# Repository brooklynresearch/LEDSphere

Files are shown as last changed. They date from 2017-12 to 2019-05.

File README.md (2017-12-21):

# LEDSphere
Code for controlling a matrix of LED Spheres

## Embedded Code
This folder is for any code that will be needed for the individual spheres

## Controller Code
This folder is for any code that will control full set of animations

## Eagle Files
This folder is for any PCB that will need to be designed for the spheres and control

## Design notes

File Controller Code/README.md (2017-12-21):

# Controller Code
Code for controlling a matrix of LED Spheres

## To Do
* Still defining communication protocol
* Waiting on Client for final animation and interaction

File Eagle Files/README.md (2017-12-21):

# Eagle Files
CAD files for PCB Designs.  All designs are currently tailored for the othermill and are more or less a one layer.

## Pixel Controller
Files for the individual Sphere.

## ENC28J60
Files for the ENC28J60 Breakout

## PoE Supply
Files to convert the PoE power to +5V

## To Do
* Determine Communications Protocol
* Design for SMD components and reduce profile

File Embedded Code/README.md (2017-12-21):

# Embedded Code
Code for controlling an individual sphere

## LEDSphere_NoComms_V01
Arduino Code for testing out individual functionality.  This code will need to change when proper communications protocol has been determined.

## libraries
Arduino libraries used in LEDSphere_NoComms_V01.

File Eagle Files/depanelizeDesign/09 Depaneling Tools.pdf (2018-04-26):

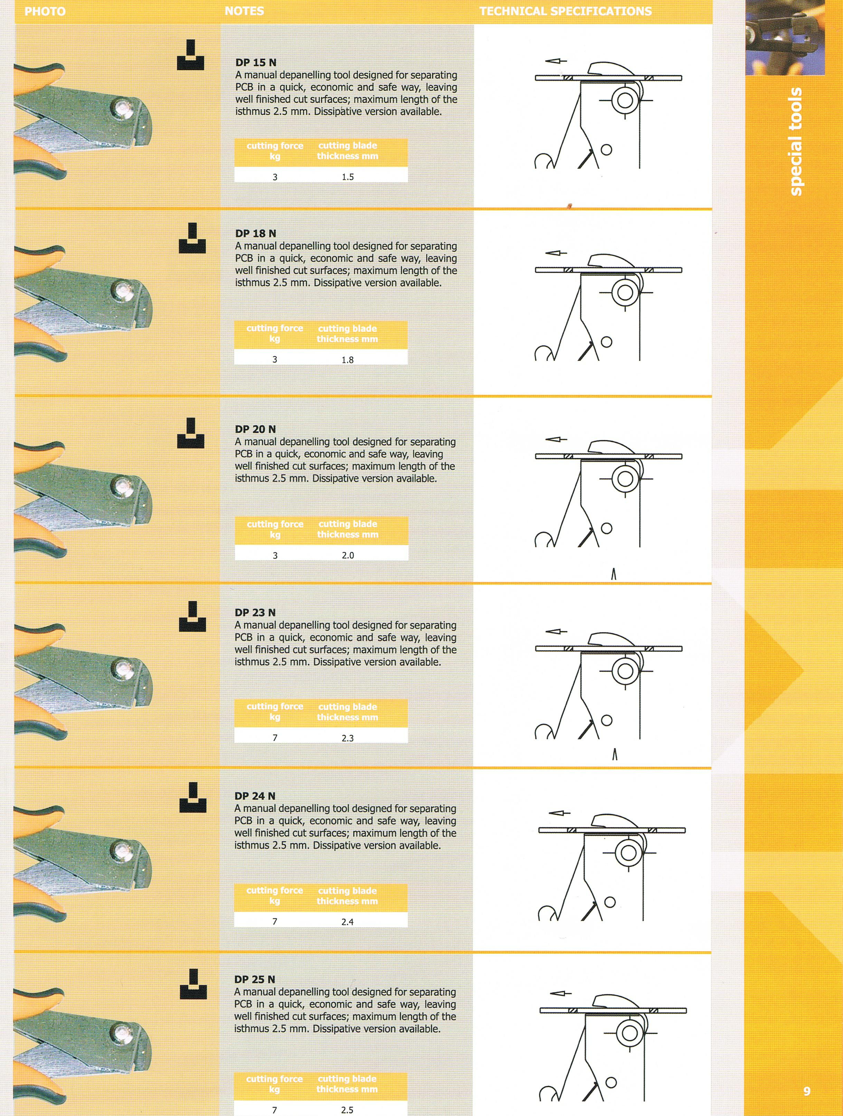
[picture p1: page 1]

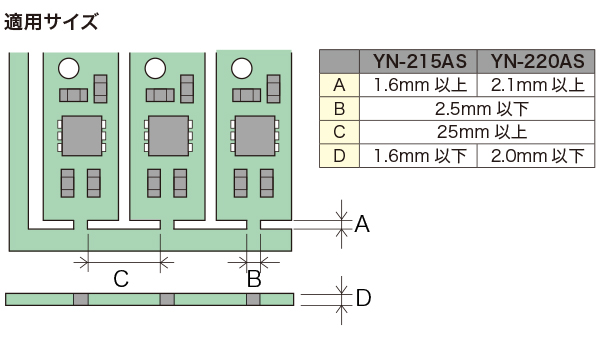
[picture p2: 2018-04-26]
Eagle Files/depanelizeDesign/YN-215_220_feature1.jpg

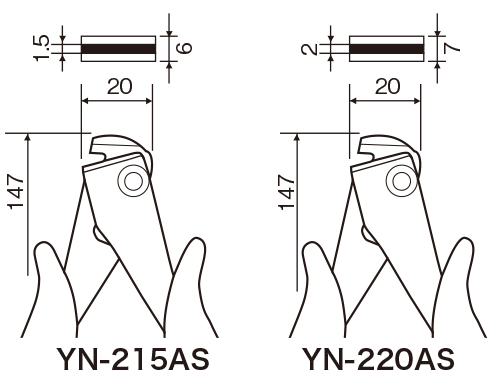
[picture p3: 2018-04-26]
Eagle Files/depanelizeDesign/yn-size.jpg

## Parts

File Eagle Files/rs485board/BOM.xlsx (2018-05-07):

Qty | Value | Device | Package | Parts | 220 板用量 | 订购来源 | 订购数量 | 运单 | 备注 | Description | LCSC | MF | MPN | OC_FARNELL | OC_NEWARK | PROD_ID | SF_ID | VALUE
5 | NC | 1,6/0,8 | 1,6/0,8 | PAD1, PAD2, PAD3, PAD4, PAD5 | 1100 |  |  |  |  | THROUGH-HOLE PAD
4 | NC | CONN_01 | 1X01 | J3, J4, J5, J6 | 880 |  |  |  |  | Single connection point. Often used as Generic Header-pin footprint for 0.1 inch spaced/style header connections
21 | 0.1uF | C-EUC0805K | C0805K | C1, C3, C4, C5, C7, C8, C9, C10, C14, C15, C16, C17, C18, C19, C20, C21, C22, C23, C24, C25, C26 | 4620 | 立创商城 | 4650 | 刚下订单 |  | CAPACITOR, European symbol | C29926
1 | 100K | R-US_R0805 | R0805 | R8 | 220 | 立创商城 | 300 | 速尔快递 880377521175 |  | RESISTOR, American symbol | C96346
5 | 10K | R-US_R0805 | R0805 | R1, R5, R6, R7, R14 | 1100 | 立创商城 | 1200 | 速尔快递 880377521175 |  | RESISTOR, American symbol | C17414
4 | 10uF | C-EUC0805K | C0805K | C2, C6, C12, C38 | 880 | 立创商城 | 900 | 速尔快递 880377521175 |  | CAPACITOR, European symbol | C92341
1 | NC | R-US_R0805 | R0805 | R11 | 220 |  |  |  |  | RESISTOR, American symbol
1 | 150pF | C-EUC0805K | C0805K | C36 | 220 | 立创商城 | 300 | 速尔快递 880377521175 |  | CAPACITOR, European symbol | C152846
1 | 158K | R-US_R0805 | R0805 | R17 | 220 | 立创商城 | 300 | 速尔快递 880377521175 |  | RESISTOR, American symbol | C104013
1 | 15uH | SLF12575T | SLF12575 | L1 | 220 | 淘宝 | 443 | 中通快递 632236278536 | 下单下多了。多余物料可以退 |  | C136211
1 | 16MHz | RESONATOR-16MHZSMD_3.2X1.3 | RESONATOR-SMD-3.2X1.3 | Y1 | 220 | 立创商城 | 225 | 速尔快递 880377521175 |  | 16MHz Resonator | C91584 |  |  |  |  | XTAL-08900 |  | 16MHz
1 | 17.4K | R-US_R0805 | R0805 | R15 | 220 | 立创商城 | 300 | 速尔快递 880377521175 |  | RESISTOR, American symbol | C144583
2 | 1K | R-US_R0805 | R0805 | R12, R13 | 440 | 立创商城 | 500 | 速尔快递 880377521175 |  | RESISTOR, American symbol | C115316
10 | 1uF 100V | 10UF-1206-6.3V-20% | 1206 | C13, C27, C28, C29, C30, C31, C32, C33, C34, C35 | 2200 | 立创商城 | 2230 | 刚下订单 |  | 10.0¬µF ceramic capacitors | C91151 |  |  |  |  | CAP-10057 |  | 10uF
1 | 200K | R-US_R0805 | R0805 | R16 | 220 | 立创商城 | 300 | 速尔快递 880377521175 |  | RESISTOR, American symbol | C17539
1 | 210K | R-US_R0805 | R0805 | R9 | 220 | 立创商城 | 300 | 速尔快递 880377521175 |  | RESISTOR, American symbol | C170839
1 | 40.2k | R-US_R0805 | R0805 | R10 | 220 | 立创商城 | 300 | 速尔快递 880377521175 |  | RESISTOR, American symbol | C104303
6 | 5819 | DIODESOD-123 | SOD-123 | D1, D2, D3, D4, D5, D6 | 1320 | 立创商城 | 1360 | 速尔快递 880377521175 |  | Diode | C64885
1 | ATMEGA328P_TQFP | ATMEGA328P_TQFP | TQFP32-08 | U1 | 220 | 立创商城 | 220 | 速尔快递 880377521175 |  | Popular 328P in QFP | C14877 |  |  |  |  | IC-09069 |  | ATMEGA328P_TQFP
1 | NC | AVR_SPI_PROG_3X2PTH | 2X3 | J1 | 220 |  |  |  |  | AVR ISP 6 Pin
1 | B280-13-F | DIODE-DO214AA | DO214AA | D20 | 220 | 立创商城 | 225 | 速尔快递 880377521175 |  | DIODE | C134445
3 | NC | MOSFET-NCH-AO3404A | SOT23-3 | Q1, Q2, Q3 | 660 |  |  |  |  | N-channel MOSFETs |  |  |  |  |  | TRANS-12988 |  | 5.8A/30V/35mŒ©
3 | NC | R-US_R0805 | R0805 | R2, R3, R4 | 660 |  |  |  |  | RESISTOR, American symbol
1 | LIS3DH | LIS3DH | LGA-16-3X3 | U2 | 220 | 立创商城 | 225 | 速尔快递 880377521175 |  | ST Microelectronics LIS3DH 3-Axis +/-2/4/8/16g SPI/I2C Accelerometer | C15134 |  |  |  |  | IC-13419 | N/A
1 | MP2562 | MP2562 | SO08 | IC2 | 220 | 立创商城 | 225 | 速尔快递 880377521175 |  |  | C93647
1 | RA 6Pin SMD | CONN_06SMD | 1X06-SMD_RA_MALE | J2 | 220 | 淘宝 | 40 | 申通快递 3359443476496 | 一根40排针可以拆出6根6针 | Multi connection point. Often used as Generic Header-pin footprint for 0.1 inch spaced/style header connections |  |  |  |  |  | CONN-08971 |  | RA 6Pin SMD
2 | RJ45-8P8C-8L-B | RJ45-8P8C-8L-B | RJ45-SHIELD-DS1128-S80BP | X1, X3 | 440 | 淘宝 | 460 | 韵达快递 3967711041128 |  | CORCOM Modular RJ Jacks No Shield | C86586 | TYCO ELECTRONICS | RJ45-8L-B | 1279843 | 52K4445
1 | SP485 | RS485SOIC | SO08 | U3 | 220 | 立创商城 | 220 | 速尔快递 880377521175 |  | RS-485 Transceiver | C6855 |  |  |  |  | IC-09388 |  | MAX3485CSA
12 | WS2812B | WS2812B | WS2812B | D7, D8, D9, D10, D11, D12, D13, D14, D15, D16, D17, D18 | 2640 | 立创商城 | 2650 | 速尔快递 880377521175 |  | WS2812B SMD addressable RGB LED | C114585 |  |  |  |  | DIO-12503 |  | WS2812B
1 | XC6206P332MR | MCP1703CB | SOT23 | IC1 | 220 | 立创商城 | 225 | 速尔快递 880377521175 |  | 250 mA, 16V, Low Quiescent Current LDO Regulator | C5446

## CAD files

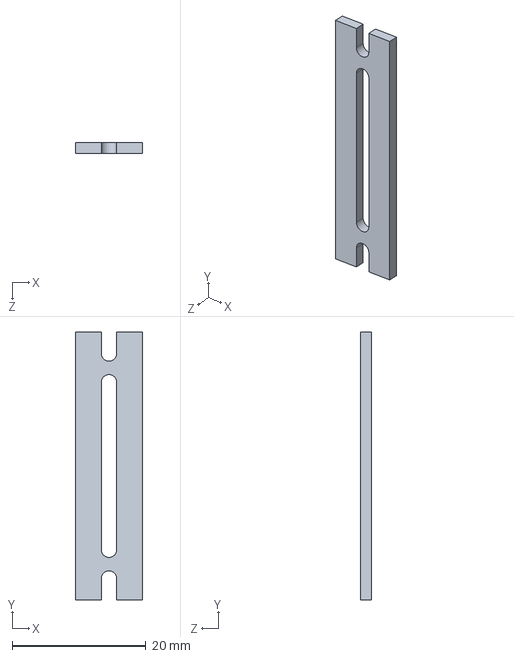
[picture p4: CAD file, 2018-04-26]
Eagle Files/depanelizeDesign/depanelizeTest.SLDPRT
10.0 x 40.0 x 1.60 mm

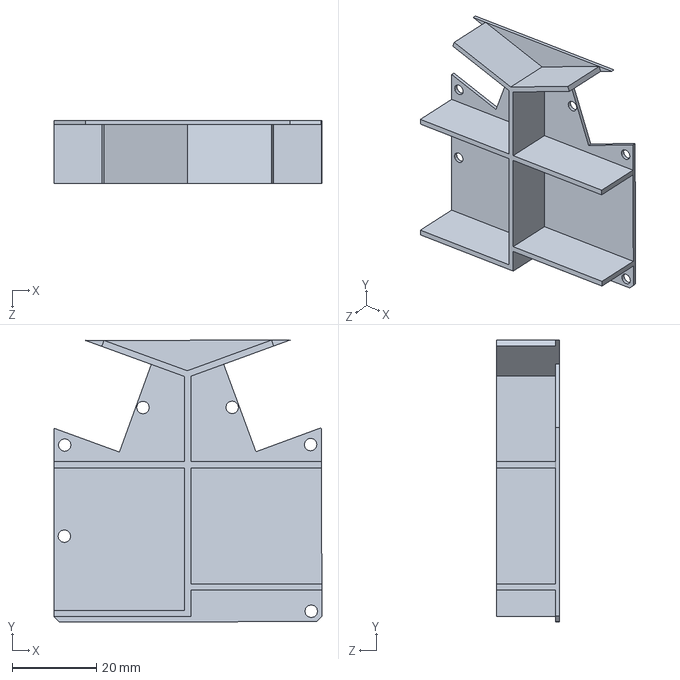
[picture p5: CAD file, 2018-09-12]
Eagle Files/rs485board/version1_24V/supportSolder.SLDPRT
63.5 x 66.8 x 15.0 mm

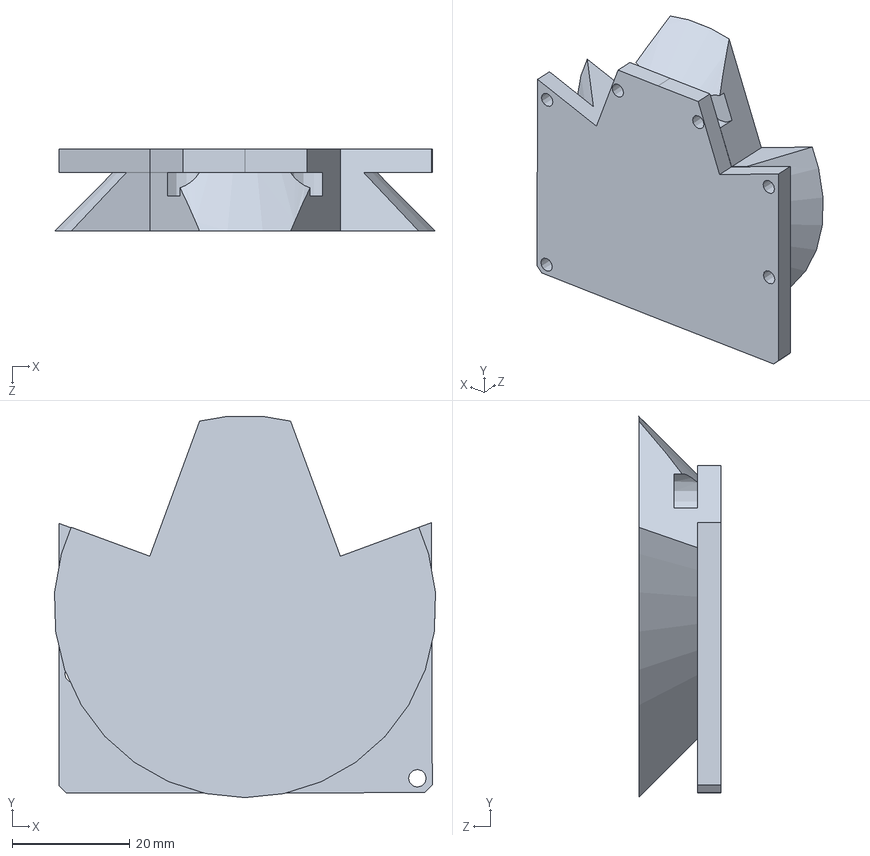
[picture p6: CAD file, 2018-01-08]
Eagle Files/rs485board/version1_24V/support.SLDPRT
64.8 x 64.9 x 14.0 mm

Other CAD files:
Eagle Files/depanelizeDesign/depanelizeTest.STL
Eagle Files/rs485board/version1_24V/support.STL

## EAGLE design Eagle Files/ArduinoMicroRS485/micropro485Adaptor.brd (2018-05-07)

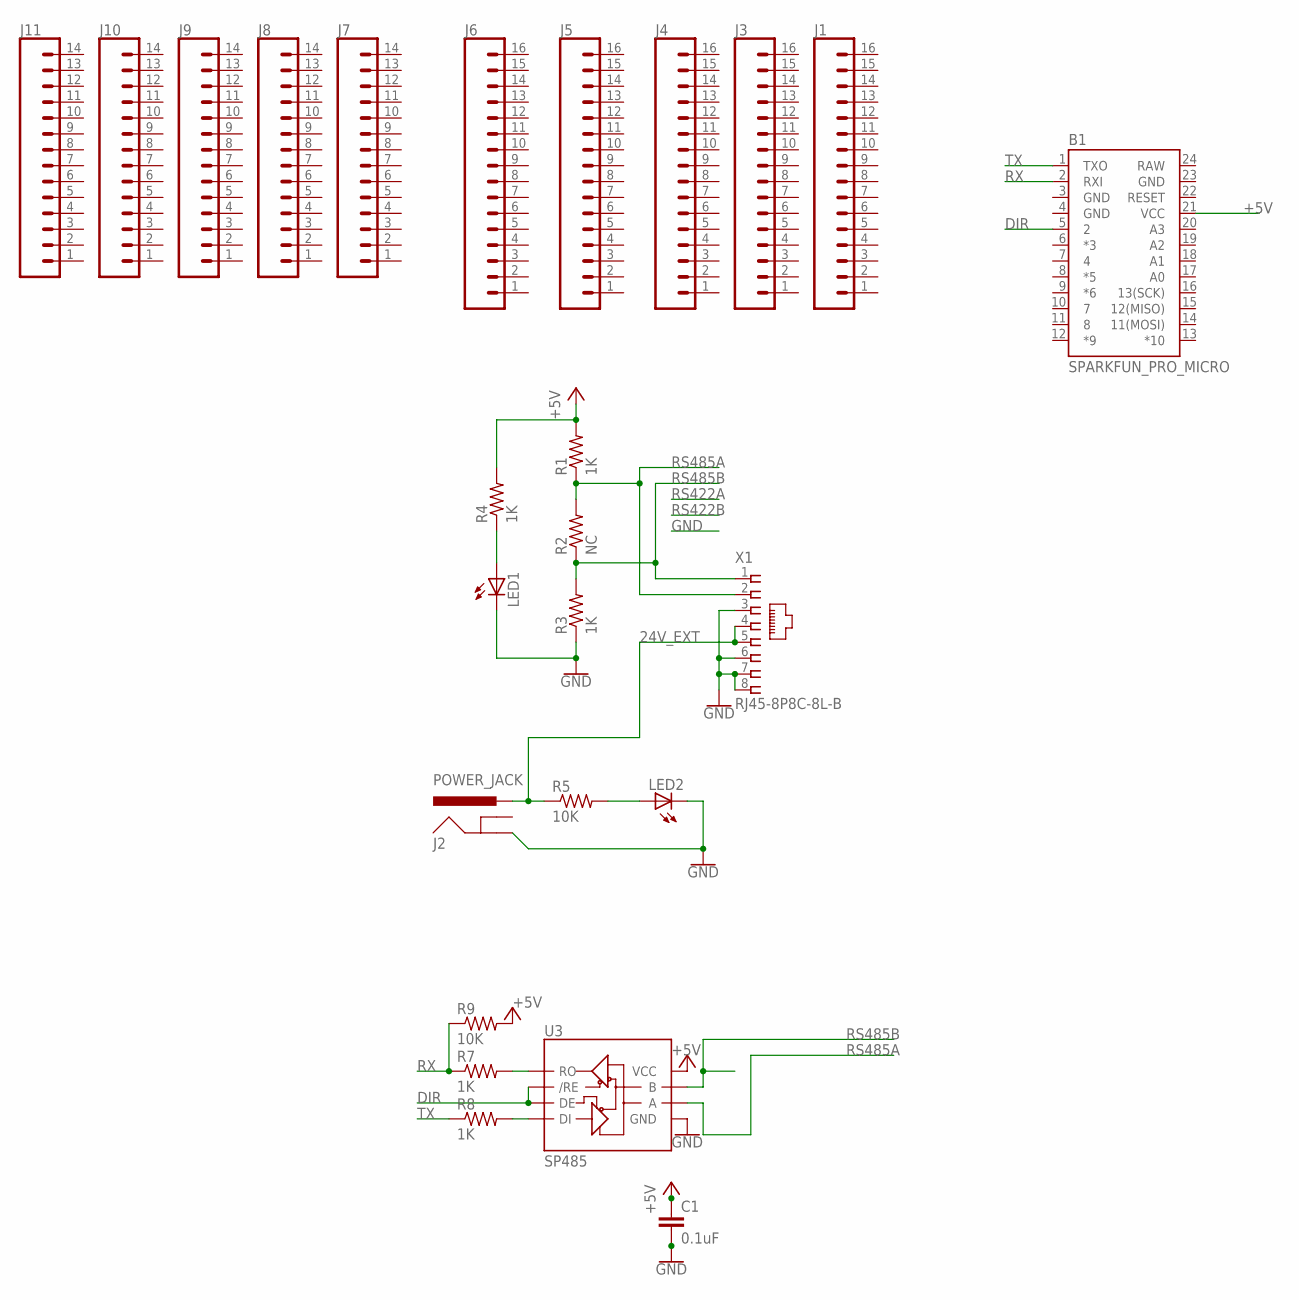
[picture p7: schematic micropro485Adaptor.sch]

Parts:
B1: SPARKFUN_PRO_MICRO
C1: 0.1uF; C0805K; LCSC C29926
J1, J3, J4, J5, J6: CONN_161X16_NO_SILK; 1X16_NO_SILK
J2: POWER_JACK; POWER_JACK_PTH
J7, J8, J9, J10, J11: CONN_14NO_SILK; 1X14_NO_SILK
LED1, LED2: LEDCHIP-LED0805; CHIP-LED0805
R1, R3, R4: 1K; R0805
R2: NC; R0805
R5, R9: 10K; R0805; LCSC C17414
R7, R8: 1K; R0805; LCSC C115316
U3: SP485; SO08; LCSC C6855
X1: RJ45-8P8C-8L-B; RJ45-SHIELD-DS1128-S80BP

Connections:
24V_EXT: J2.PWR, R5.1, X1.4, X1.5
+5V: B1.21 (VCC), C1.1, R1.2, R4.2, R9.2, U3.8 (VCC)
DIR: B1.5 (2), U3.2 (/RE), U3.3 (DE)
GND: B1.3 (GND), B1.4 (GND), B1.23 (GND), C1.2, J2.GND, LED1.C, LED2.C, R3.1, U3.5 (GND), X1.3, X1.6, X1.7, X1.8
unnamed: LED2.A, R5.2
unnamed: LED1.A, R4.1
unnamed: R7.2, U3.1 (RO)
unnamed: R8.2, U3.4 (DI)
RAW: B1.24 (RAW)
RS485A: R1.1, R2.2, U3.6 (A), X1.2
RS485B: R2.1, R3.2, U3.7 (B), X1.1
RX: B1.2 (RXI), R7.1, R9.1
TX: B1.1 (TXO), R8.1

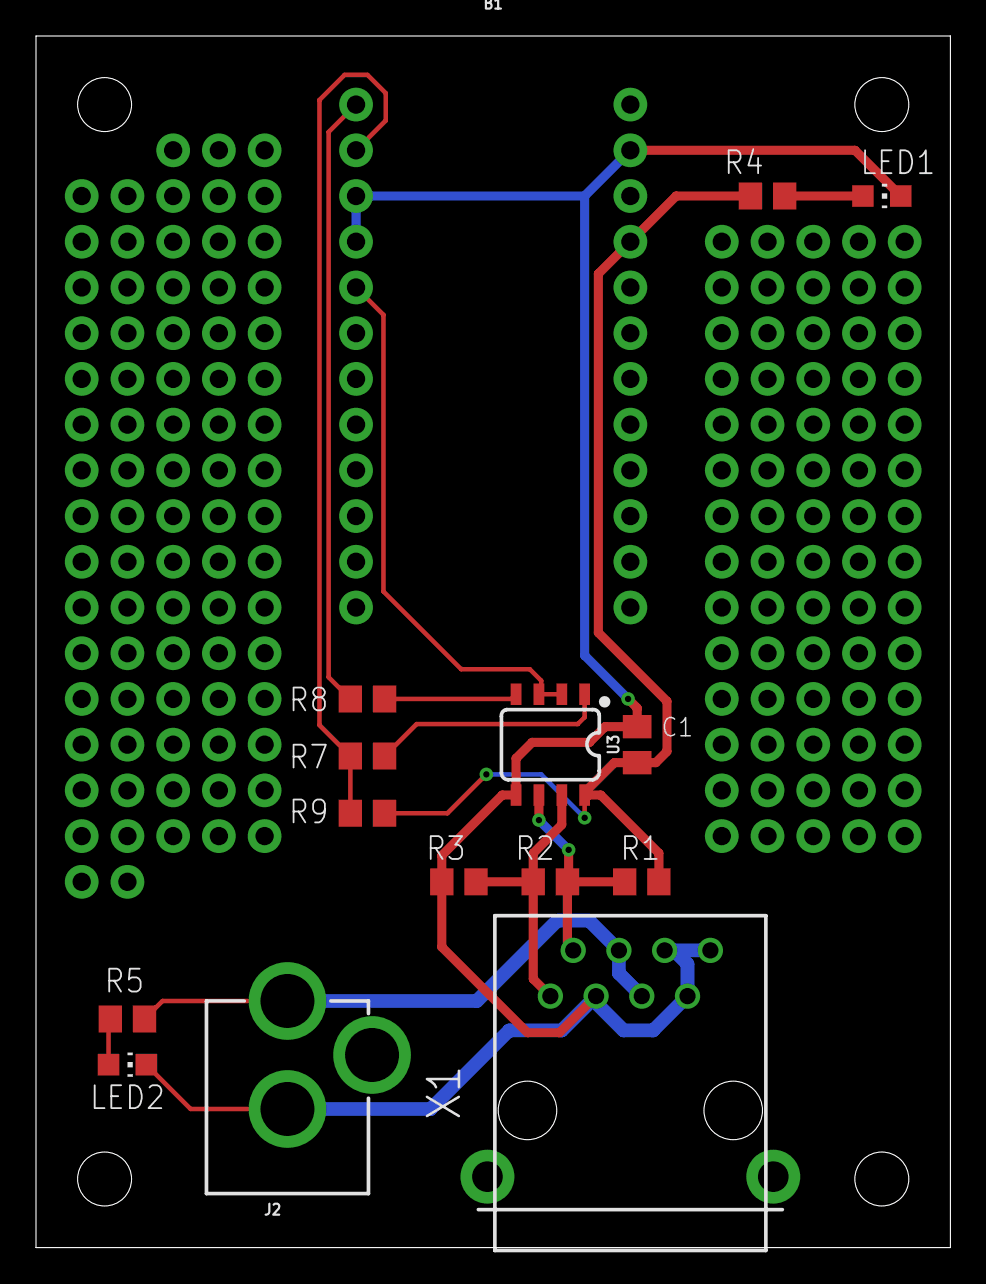
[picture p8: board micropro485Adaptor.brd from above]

Board: 2 copper layers, 50.8 x 67.3 mm, 25 parts (0 on the bottom side), 12 nets.

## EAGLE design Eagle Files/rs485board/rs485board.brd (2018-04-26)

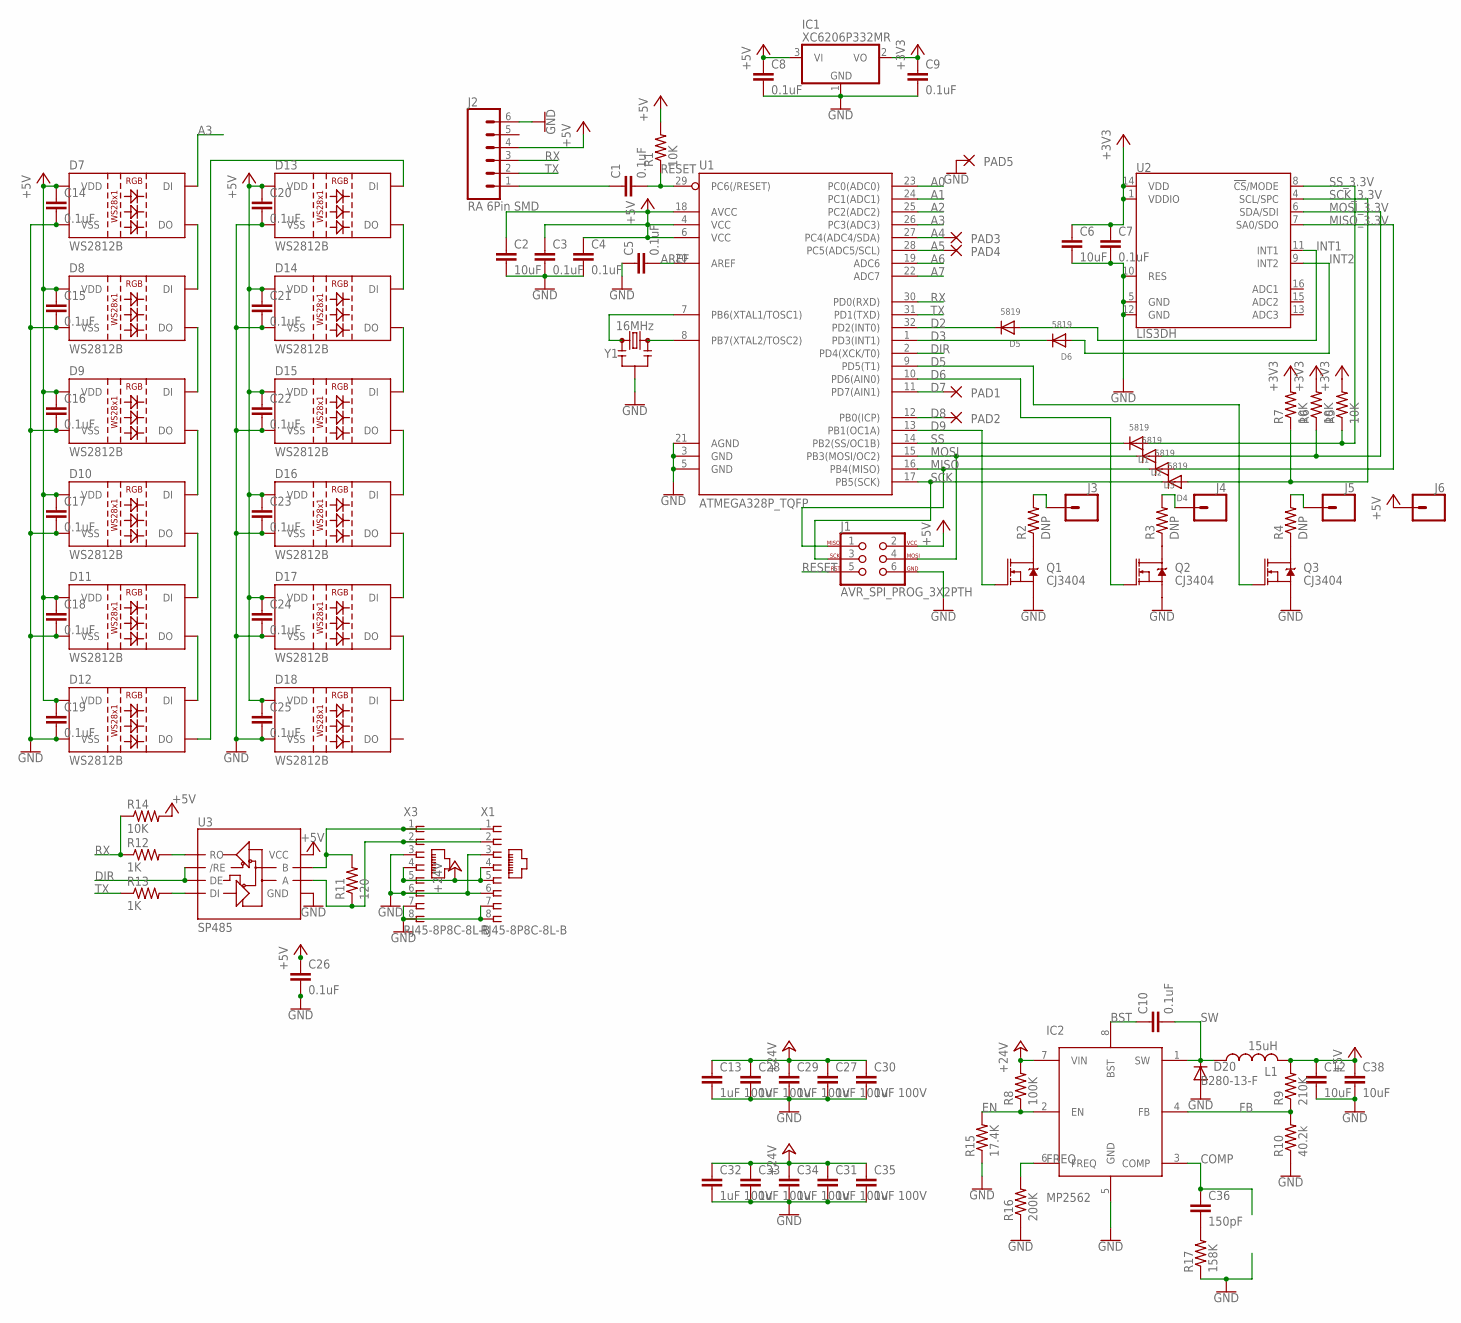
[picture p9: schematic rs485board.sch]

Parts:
C1, C3, C4, C5, C7, C8, C9, C10, C14, C15, C16, C17, C18, C19, C20, C21, C22, C23, C24, C25, C26: 0.1uF; C0805K; LCSC C29926
C2, C6, C12, C38: 10uF; C0805K; LCSC C92341
C13, C27, C28, C29, C30, C31, C32, C33, C34, C35: 1uF 100V; 1206; LCSC C91151
C36: 150pF; C0805K; LCSC C152846
D1, D2, D3, D4, D5, D6: 5819; SOD-123; LCSC C64885
D7, D8, D9, D10, D11, D12, D13, D14, D15, D16, D17, D18: WS2812B; LCSC C114585
D20: B280-13-F; DO214AA; LCSC C134445
IC1: XC6206P332MR; SOT23; LCSC C5446
IC2: MP2562; SO08; LCSC C93647
J1: AVR_SPI_PROG_3X2PTH; 2X3
J2: RA 6Pin SMD; 1X06-SMD_RA_MALE
J3, J4, J5, J6: CONN_01; 1X01
L1: 15uH; SLF12575; LCSC C136211
PAD1, PAD2, PAD3, PAD4, PAD5: 1,6/0,8
Q1, Q2, Q3: CJ3404; SOT23-3
R1, R5, R6, R7, R14: 10K; R0805; LCSC C17414
R2, R3, R4: DNP; R0805
R8: 100K; R0805; LCSC C96346
R9: 210K; R0805; LCSC C170839
R10: 40.2k; R0805; LCSC C104303
R11: 120; R0805
R12, R13: 1K; R0805; LCSC C115316
R15: 17.4K; R0805; LCSC C144583
R16: 200K; R0805; LCSC C17539
R17: 158K; R0805; LCSC C104013
U1: ATMEGA328P_TQFP; TQFP32-08; LCSC C14877
U2: LIS3DH; LGA-16-3X3; LCSC C15134
U3: SP485; SO08; LCSC C6855
X1, X3: RJ45-8P8C-8L-B; RJ45-SHIELD-DS1128-S80BP; LCSC C86586
Y1: 16MHz; RESONATOR-SMD-3.2X1.3; LCSC C91584

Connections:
+3V3: C6.1, C7.1, C9.1, IC1.2 (VO), R5.2, R6.2, R7.2, U2.1 (VDDIO), U2.14 (VDD)
+5V: C2.1, C3.1, C4.1, C8.1, C12.1, C14.1, C15.1, C16.1, C17.1, C18.1, C19.1, C20.1, C21.1, C22.1, C23.1, C24.1, C25.1, C26.1, C38.1, D7.1 (VDD), D8.1 (VDD), D9.1 (VDD), D10.1 (VDD), D11.1 (VDD), D12.1 (VDD), D13.1 (VDD), D14.1 (VDD), D15.1 (VDD), D16.1 (VDD), D17.1 (VDD), D18.1 (VDD), IC1.3 (VI), J1.2, J2.4, J6.1, L1.P$2 (2), R1.2, R9.2, R14.2, U1.4 (VCC), U1.6 (VCC), U1.18 (AVCC), U3.8 (VCC)
+24V: C13.1, C27.1, C28.1, C29.1, C30.1, C31.1, C32.1, C33.1, C34.1, C35.1, IC2.7 (VIN), R8.2, X1.4, X1.5, X3.4, X3.5
A0: U1.23 (PC0(ADC0))
A1: U1.24 (PC1(ADC1))
A2: U1.25 (PC2(ADC2))
A3: D7.4 (DI), U1.26 (PC3(ADC3))
A4: PAD3.1, U1.27 (PC4(ADC4/SDA))
A5: PAD4.1, U1.28 (PC5(ADC5/SCL))
A6: U1.19 (ADC6)
A7: U1.22 (ADC7)
AREF: C5.2, U1.20 (AREF)
BST: C10.1, IC2.8 (BST)
COMP: C36.1, IC2.3 (COMP)
D2: D5.C, U1.32 (PD2(INT0))
D3: D6.C, U1.1 (PD3(INT1))
D5: Q3.1 (G), U1.9 (PD5(T1))
D6: Q2.1 (G), U1.10 (PD6(AIN0))
D7: PAD1.1, U1.11 (PD7(AIN1))
D8: PAD2.1, U1.12 (PB0(ICP))
D9: Q1.1 (G), U1.13 (PB1(OC1A))
DIR: U1.2 (PD4(XCK/T0)), U3.2 (/RE), U3.3 (DE)
EN: IC2.2 (EN), R8.1, R15.2
FB: IC2.4 (FB), R9.1, R10.2
FREQ: IC2.6 (FREQ), R16.2
GND: C2.2, C3.2, C4.2, C5.1, C6.2, C7.2, C8.2, C9.2, C12.2, C13.2, C14.2, C15.2, C16.2, C17.2, C18.2, C19.2, C20.2, C21.2, C22.2, C23.2, C24.2, C25.2, C26.2, C27.2, C28.2, C29.2, C30.2, C31.2, C32.2, C33.2, C34.2, C35.2, C38.2, D7.3 (VSS), D8.3 (VSS), D9.3 (VSS), D10.3 (VSS), D11.3 (VSS), D12.3 (VSS), D13.3 (VSS), D14.3 (VSS), D15.3 (VSS), D16.3 (VSS), D17.3 (VSS), D18.3 (VSS), D20.A, IC1.1 (GND), IC2.5 (GND), J1.6, J2.6, PAD5.1, Q1.2 (S), Q2.2 (S), Q3.2 (S), R10.1, R15.1, R16.1, R17.1, U1.3 (GND), U1.5 (GND), U1.21 (AGND), U2.5 (GND), U2.10 (RES), U2.12 (GND), U3.5 (GND), X1.3, X1.6, X1.7, X1.8, X3.3, X3.6, X3.7, X3.8, Y1.2
INT1: D5.A, U2.11 (INT1)
INT2: D6.A, U2.9 (INT2)
MISO: D3.C, J1.1, U1.16 (PB4(MISO))
MISO_3.3V: D3.A, U2.7 (SA0/SDO)
MOSI: D2.C, J1.4, U1.15 (PB3(MOSI/OC2))
MOSI_3.3V: D2.A, R6.1, U2.6 (SDA/SDI)
unnamed: Q1.3 (D), R2.1
unnamed: D7.2 (DO), D8.4 (DI)
unnamed: D8.2 (DO), D9.4 (DI)
unnamed: J3.1, R2.2
unnamed: Q2.3 (D), R3.1
unnamed: J4.1, R3.2
unnamed: Q3.3 (D), R4.1
unnamed: J5.1, R4.2
unnamed: D9.2 (DO), D10.4 (DI)
unnamed: D10.2 (DO), D11.4 (DI)
unnamed: D11.2 (DO), D12.4 (DI)
unnamed: D12.2 (DO), D13.4 (DI)
unnamed: D13.2 (DO), D14.4 (DI)
unnamed: D14.2 (DO), D15.4 (DI)
unnamed: D15.2 (DO), D16.4 (DI)
unnamed: D16.2 (DO), D17.4 (DI)
unnamed: D17.2 (DO), D18.4 (DI)
unnamed: C36.2, R17.2
unnamed: R12.2, U3.1 (RO)
unnamed: R13.2, U3.4 (DI)
RESET: C1.2, J1.5, R1.1, U1.29 (PC6(/RESET))
RESET_EXT: C1.1, J2.1
RS485A: R11.1, U3.6 (A), X1.2, X3.2
RS485B: R11.2, U3.7 (B), X1.1, X3.1
RX: J2.3, R12.1, R14.1, U1.30 (PD0(RXD))
SCK: D4.C, J1.3, U1.17 (PB5(SCK))
SCK_3.3V: D4.A, R7.1, U2.4 (SCL/SPC)
SS: D1.C, U1.14 (PB2(SS/OC1B))
SS_3.3V: D1.A, R5.1, U2.8 (!CS!/MODE)
SW: C10.2, D20.C, IC2.1 (SW), L1.P$1 (1)
TX: J2.2, R13.1, U1.31 (PD1(TXD))
XTAL1: U1.7 (PB6(XTAL1/TOSC1)), Y1.1
XTAL2: U1.8 (PB7(XTAL2/TOSC2)), Y1.3

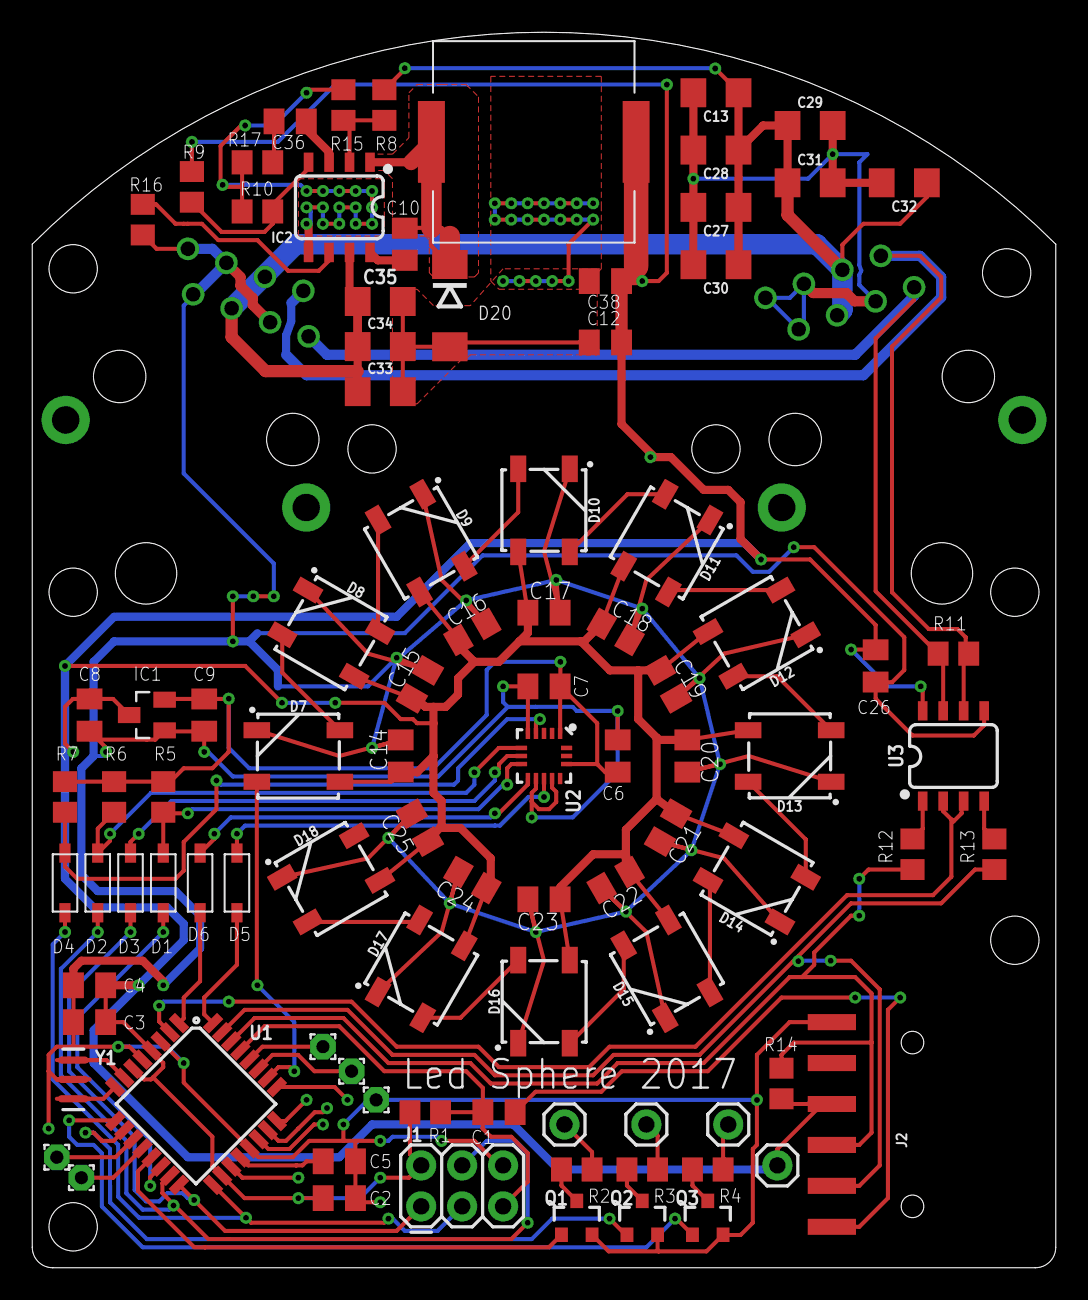
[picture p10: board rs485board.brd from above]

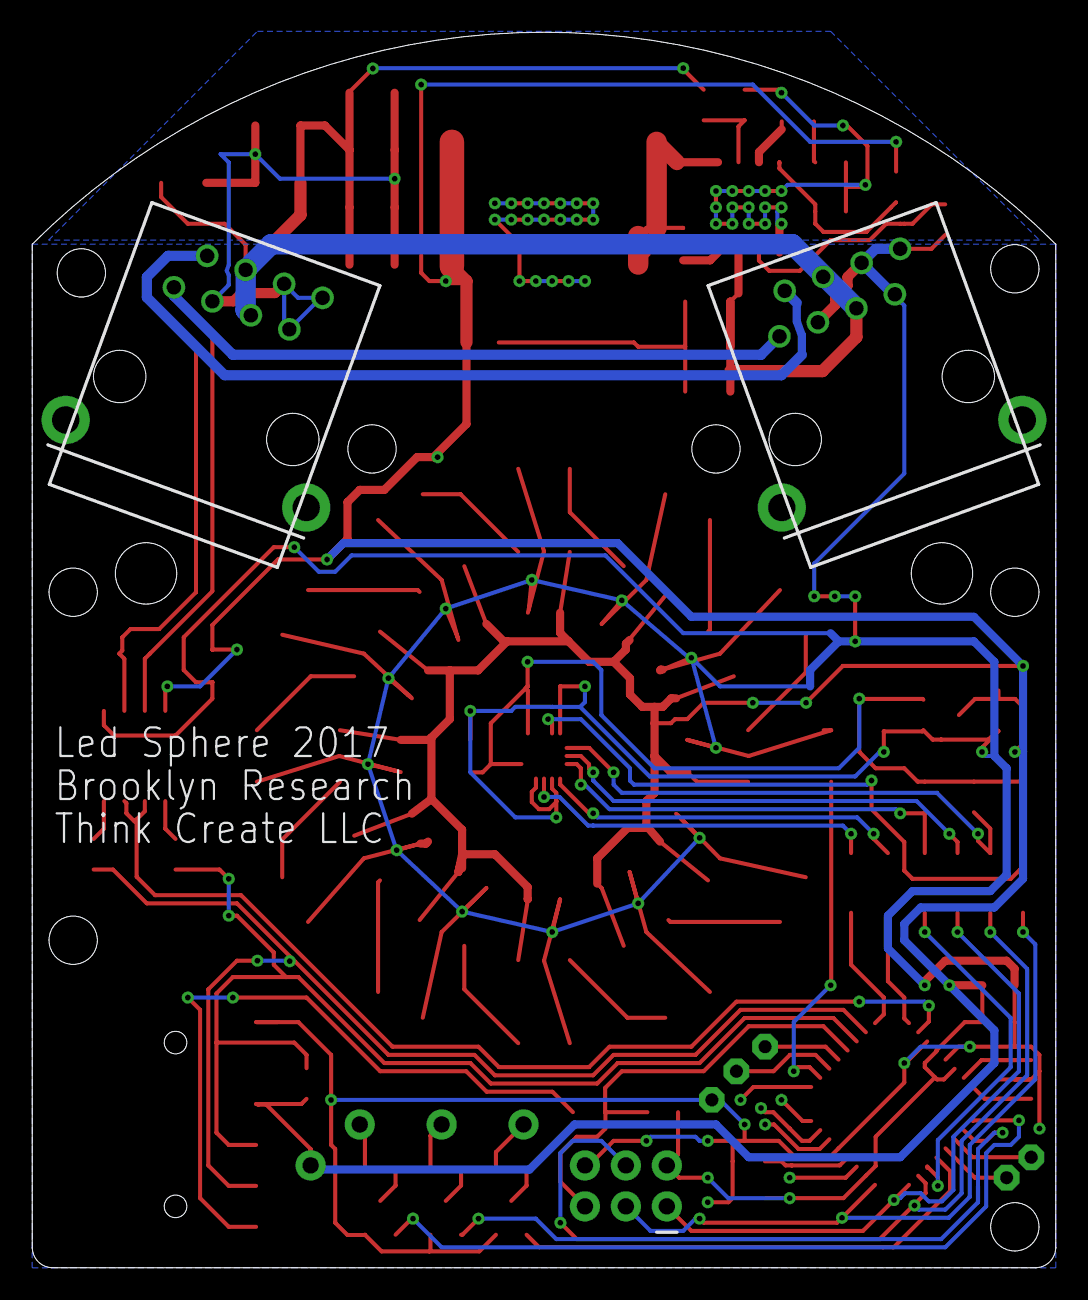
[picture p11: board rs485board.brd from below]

Board: 2 copper layers, 63.5 x 76.7 mm, 95 parts (2 on the bottom side), 60 nets.

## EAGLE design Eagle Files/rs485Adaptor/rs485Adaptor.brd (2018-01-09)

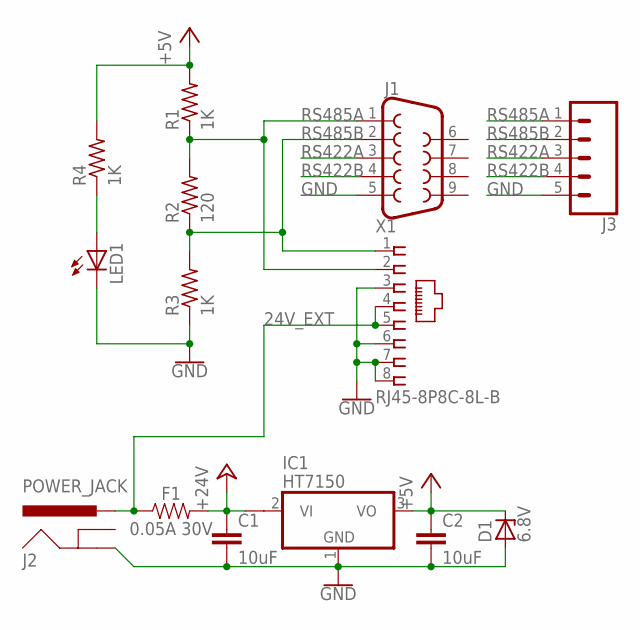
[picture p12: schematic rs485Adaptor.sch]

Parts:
C1: 10uF; 1206
C2: 10uF; C0805K
D1: 6.8V; SOD80C
F1: 0.05A 30V; 1210
IC1: HT7150; SOT89
J1: DB9FEMALE; DB9
J2: POWER_JACK; POWER_JACK_PTH
J3: CONN_05SCREW; SCREWTERMINAL-3.5MM-5
LED1: LEDCHIP-LED0805; CHIP-LED0805
R1, R3, R4: 1K; R0805
R2: 120; R0805
X1: RJ45-8P8C-8L-B; RJ45-SHIELD-DS1128-S80BP

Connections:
24V_EXT: F1.1, J2.PWR, X1.4, X1.5
+5V: C2.1, D1.C, IC1.3 (VO), R1.2, R4.2
+24V: C1.1, F1.2, IC1.2@1 (VI1)
GND: C1.2, C2.2, D1.A, IC1.1 (GND), J1.5, J2.GND, J3.5, LED1.C, R3.1, X1.3, X1.6, X1.7, X1.8
unnamed: LED1.A, R4.1
RS422A: J1.3, J3.3
RS422B: J1.4, J3.4
RS485A: J1.1, J3.1, R1.1, R2.2, X1.2
RS485B: J1.2, J3.2, R2.1, R3.2, X1.1

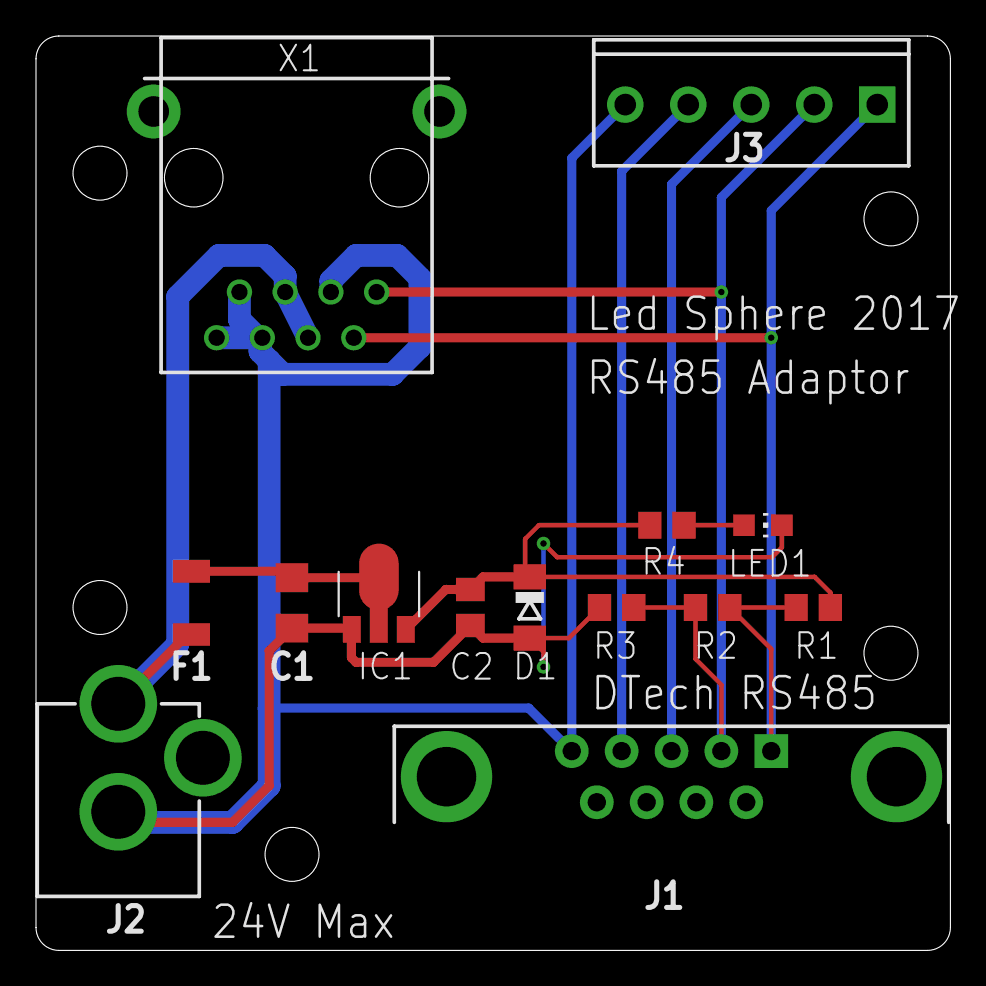
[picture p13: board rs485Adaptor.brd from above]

Board: 2 copper layers, 50.8 x 50.8 mm, 14 parts (0 on the bottom side), 9 nets.

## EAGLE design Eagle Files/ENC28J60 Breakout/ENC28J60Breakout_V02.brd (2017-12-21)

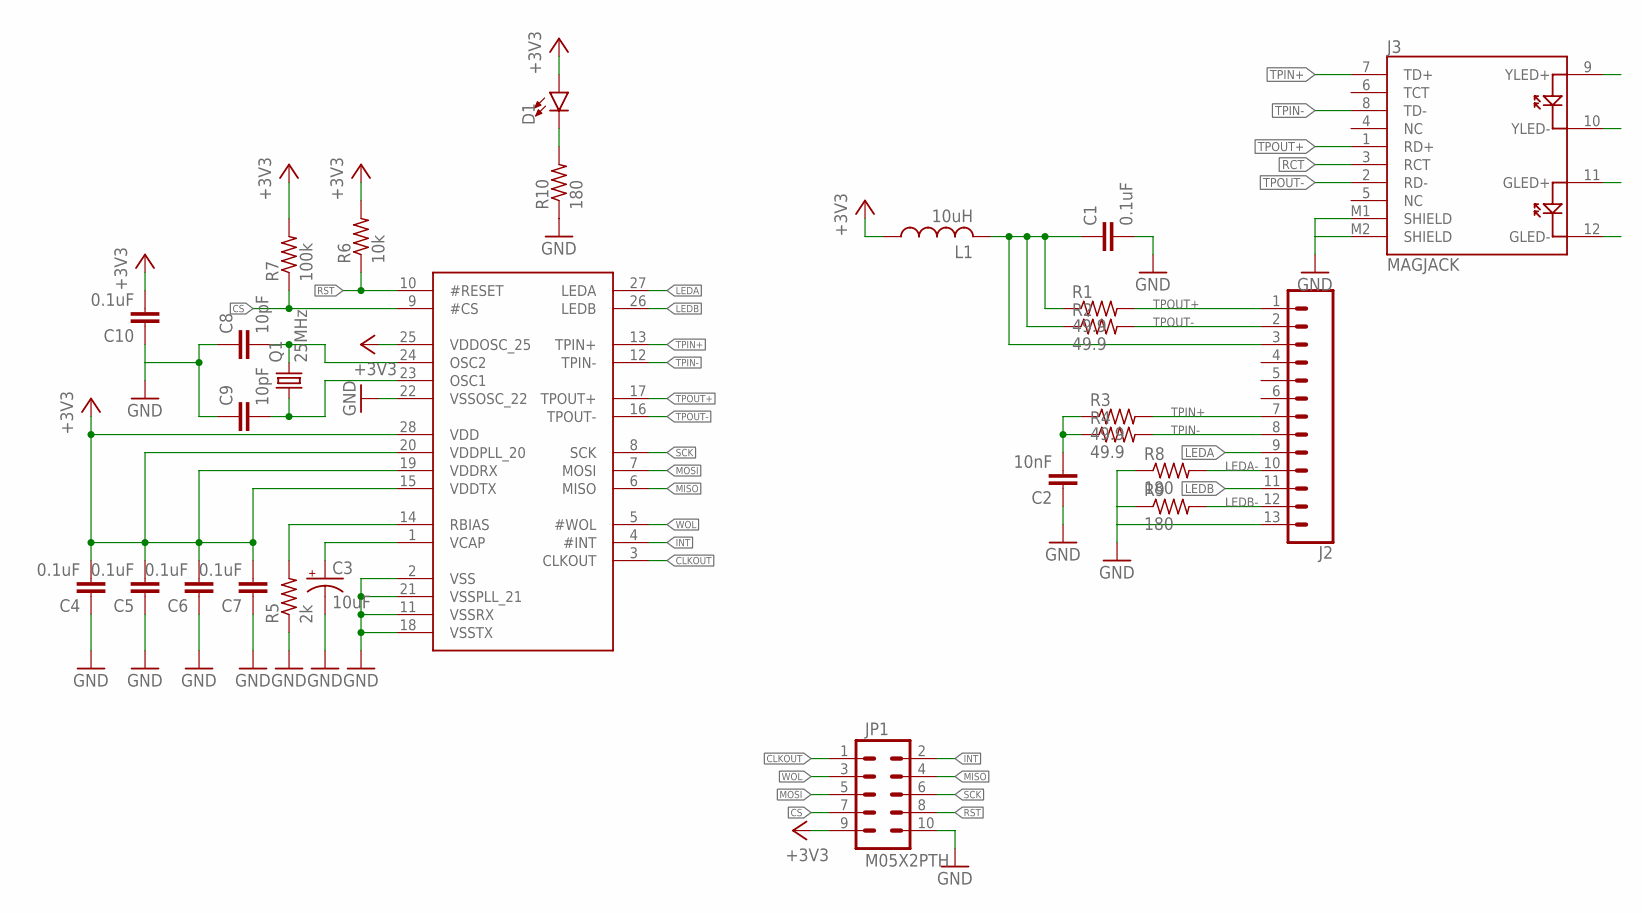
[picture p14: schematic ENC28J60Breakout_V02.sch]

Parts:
C1, C4, C5, C6, C7, C10: 0.1uF; C050-024X044
C2: 10nF; C050-024X044
C3: 10uF; E2,5-7
C8, C9: 10pF; C050-024X044
D1: LED5MM; LED_5MM
J2: CONN_13; 1X13
J3: MAGJACK
JP1: M05X2PTH; AVR_ICSP
L1: 10uH; 0204/7
Q1: 25MHz; HC49/S
R1, R2, R3, R4: 49.9; 0204/7
R5: 2k; 0204/7
R6: 10k; 0204/7
R7: 100k; 0204/7
R8, R9, R10: 180; 0204/7
U$1: ENC28J60; ENC28J60_DIP

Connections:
+3V3: C4.2, C5.2, C6.2, C7.2, C10.2, D1.A, JP1.9, L1.1, R6.2, R7.2, U$1.15 (VDDTX), U$1.19 (VDDRX), U$1.20 (VDDPLL_20), U$1.25 (VDDOSC_25), U$1.28 (VDD)
CLKOUT: JP1.1, U$1.3 (CLKOUT)
CS: JP1.7, R7.1, U$1.9 (#CS)
GND: C1.2, C2.1, C3.-, C4.1, C5.1, C6.1, C7.1, C8.1, C9.1, C10.1, J2.13, J3.M1 (SHIELD), J3.M2 (SHIELD), JP1.10, R5.1, R8.1, R9.1, R10.1, U$1.2 (VSS), U$1.11 (VSSRX), U$1.18 (VSSTX), U$1.21 (VSSPLL_21), U$1.22 (VSSOSC_22)
INT: JP1.2, U$1.4 (#INT)
LEDA: J2.9, J3.9 (YLED+), U$1.27 (LEDA)
LEDA-: J2.10, J3.10 (YLED-), R8.2
LEDB: J2.11, J3.11 (GLED+), U$1.26 (LEDB)
LEDB-: J2.12, J3.12 (GLED-), R9.2
MISO: JP1.4, U$1.6 (MISO)
MOSI: JP1.5, U$1.7 (MOSI)
unnamed: C8.2, Q1.2, U$1.24 (OSC2)
unnamed: D1.K (C), R10.2
unnamed: C9.2, Q1.1, U$1.23 (OSC1)
unnamed: C3.+, U$1.1 (VCAP)
unnamed: R5.2, U$1.14 (RBIAS)
unnamed: C2.2, R3.1, R4.1
RCT: C1.1, J2.3, J3.3 (RCT), L1.2, R1.1, R2.1
RST: JP1.8, R6.1, U$1.10 (#RESET)
SCK: JP1.6, U$1.8 (SCK)
TPIN+: J2.7, J3.7 (TD+), R3.2, U$1.13 (TPIN+)
TPIN-: J2.8, J3.8 (TD-), R4.2, U$1.12 (TPIN-)
TPOUT+: J2.1, J3.1 (RD+), R1.2, U$1.17 (TPOUT+)
TPOUT-: J2.2, J3.2 (RD-), R2.2, U$1.16 (TPOUT-)
WOL: JP1.3, U$1.5 (#WOL)

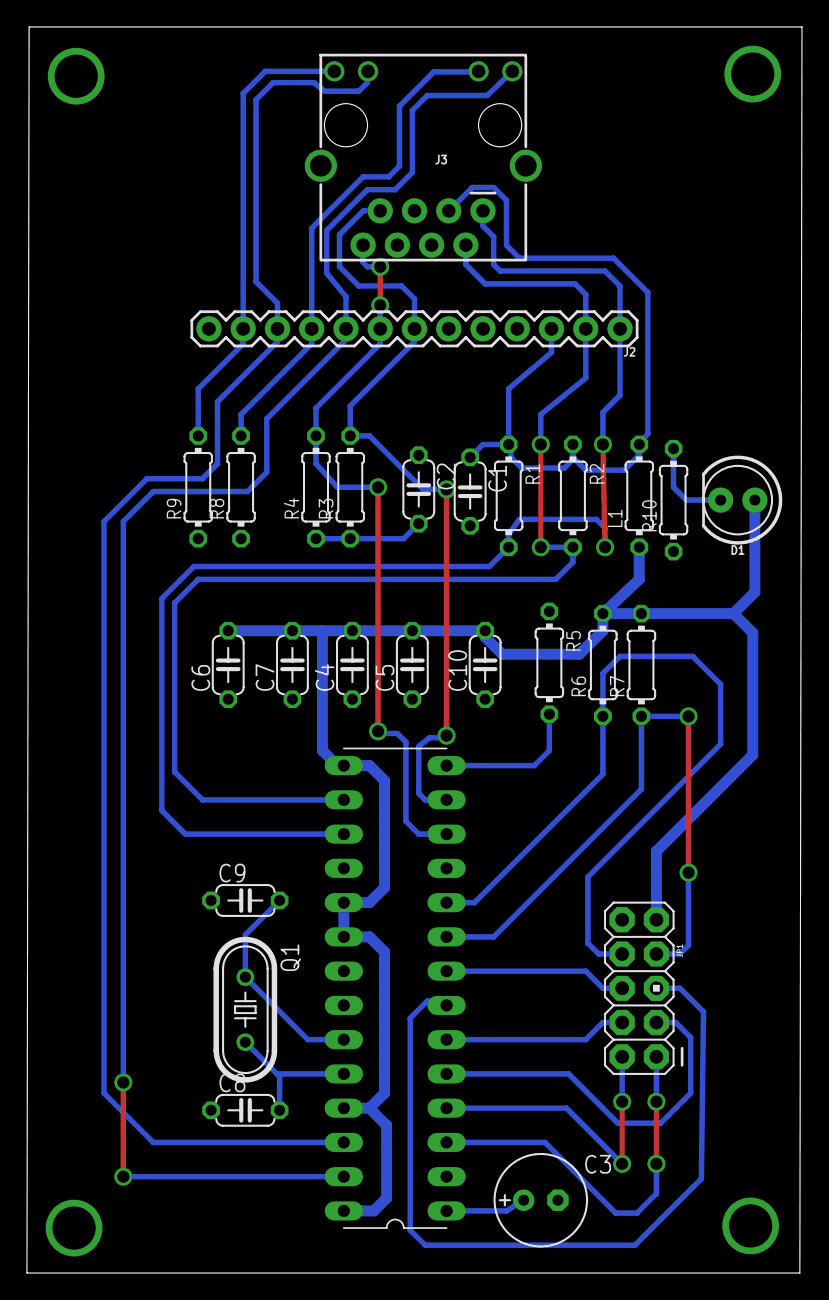
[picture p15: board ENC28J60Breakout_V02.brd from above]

Board: 2 copper layers, 57.5 x 92.4 mm, 27 parts (0 on the bottom side), 25 nets.

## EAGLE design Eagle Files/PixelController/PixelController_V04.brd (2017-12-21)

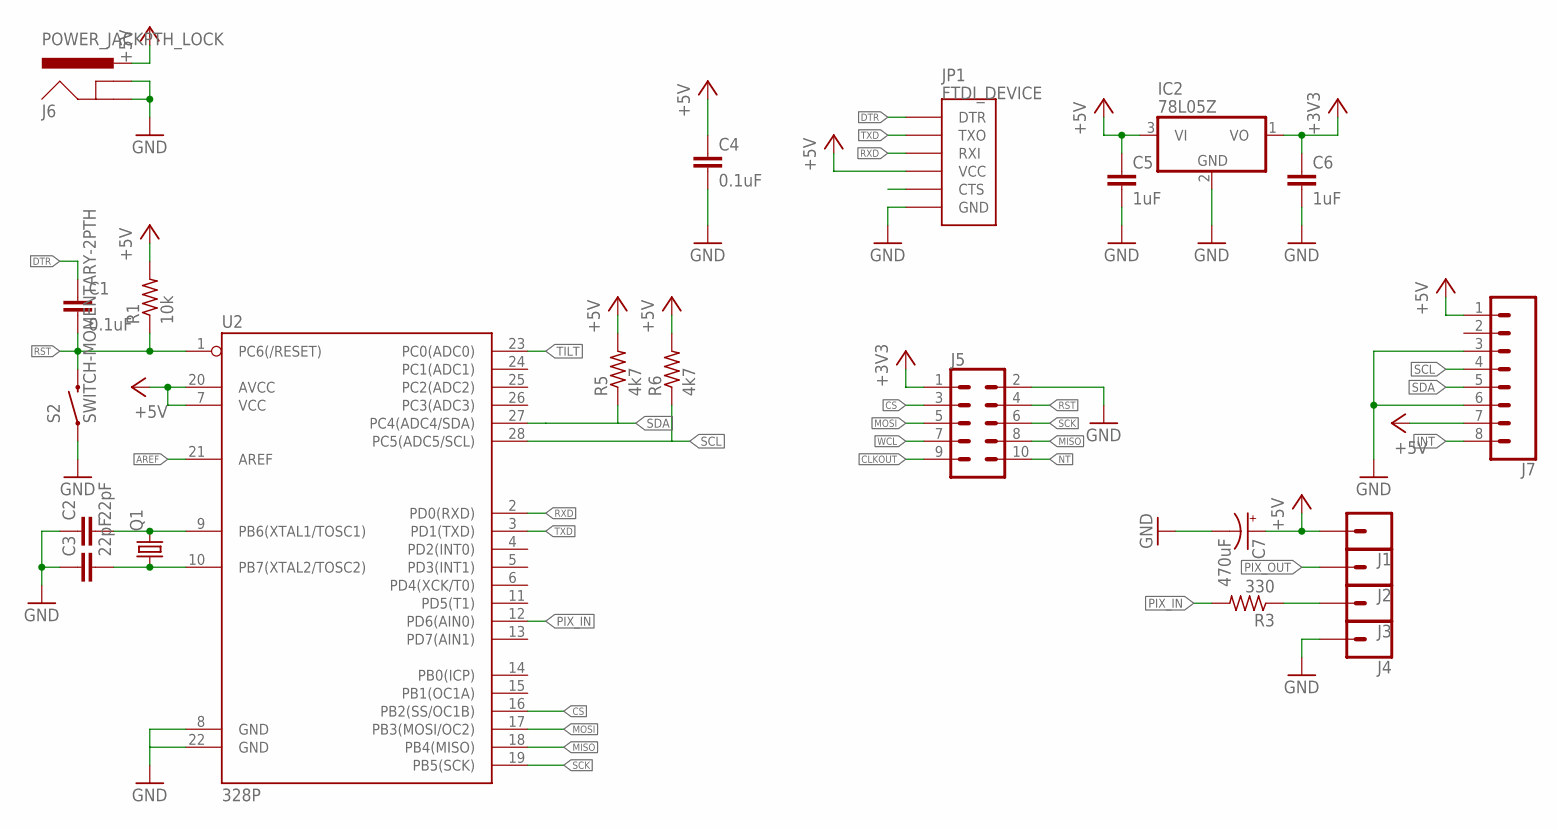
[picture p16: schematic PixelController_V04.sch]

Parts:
C1, C4: 0.1uF; C050-025X075
C2, C3: 22pF; C050-024X044
C5, C6: 1uF; C050-025X075
C7: 470uF; E3,5-8
IC2: 78L05Z; TO92
J1, J2, J3, J4: CONN_01; 1X01
J5: CONN_05X2PTH; 2X5
J6: POWER_JACKPTH_LOCK; POWER_JACK_PTH_LOCK
J7: CONN_08"; 1X08@1
JP1: FTDI_DEVICE; FTDI_DEVICE_SIDE
Q1: CRYSTALHC49U70; HC49U70
R1: 10k; 0204/7
R3: 330; 0204/7
R5, R6: 4k7; 0204/7
S2: SWITCH-MOMENTARY-2PTH; TACTILE-PTH
U2: 328P; DIP28

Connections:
+3V3: C6.1, IC2.1 (VO), J5.1
+5V: C4.1, C5.1, C7.+, IC2.3 (VI), J1.1, J6.PWR, J7.1, J7.7, JP1.P$4 (VCC), R1.2, R5.2, R6.2, U2.7 (VCC), U2.20 (AVCC)
AREF: U2.21 (AREF)
CLKOUT: J5.9
CS: J5.3, U2.16 (PB2(SS/OC1B))
DTR: C1.1, JP1.P$1 (DTR)
GND: C2.1, C3.1, C4.2, C5.2, C6.2, C7.-, IC2.2 (GND), J4.1, J5.2, J6.GND, J6.GNDBREAK, J7.3, J7.6, JP1.P$6 (GND), S2.1, U2.8 (GND), U2.22 (GND)
INT: J7.8
MISO: J5.8, U2.18 (PB4(MISO))
MOSI: J5.5, U2.17 (PB3(MOSI/OC2))
unnamed: C3.2, Q1.1, U2.10 (PB7(XTAL2/TOSC2))
unnamed: C2.2, Q1.2, U2.9 (PB6(XTAL1/TOSC1))
unnamed: J3.1, R3.1
NT: J5.10
PIX_IN: R3.2, U2.12 (PD6(AIN0))
PIX_OUT: J2.1
RST: C1.2, J5.4, R1.1, S2.3 (2), U2.1 (PC6(/RESET))
RXD: JP1.P$3 (RXI), U2.2 (PD0(RXD))
SCK: J5.6, U2.19 (PB5(SCK))
SCL: J7.4, R6.1, U2.28 (PC5(ADC5/SCL))
SDA: J7.5, R5.1, U2.27 (PC4(ADC4/SDA))
TILT: U2.23 (PC0(ADC0))
TXD: JP1.P$2 (TXO), U2.3 (PD1(TXD))
WCL: J5.7

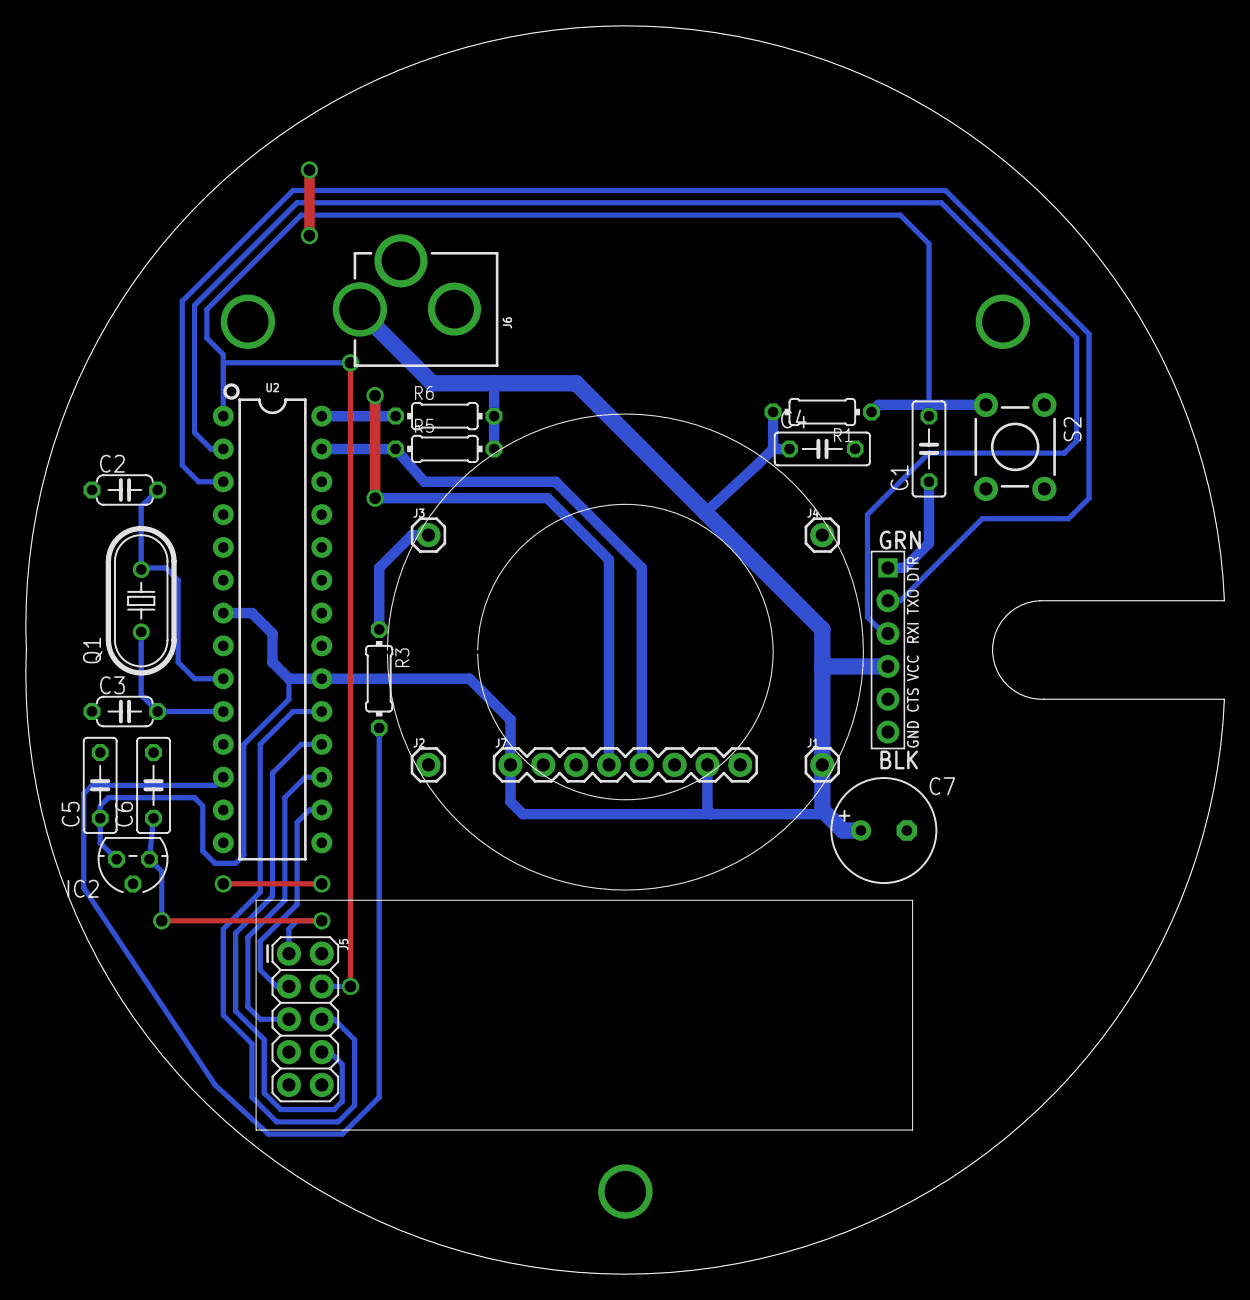
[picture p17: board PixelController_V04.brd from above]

Board: 2 copper layers, 92.7 x 96.6 mm, 23 parts (0 on the bottom side), 17 nets.

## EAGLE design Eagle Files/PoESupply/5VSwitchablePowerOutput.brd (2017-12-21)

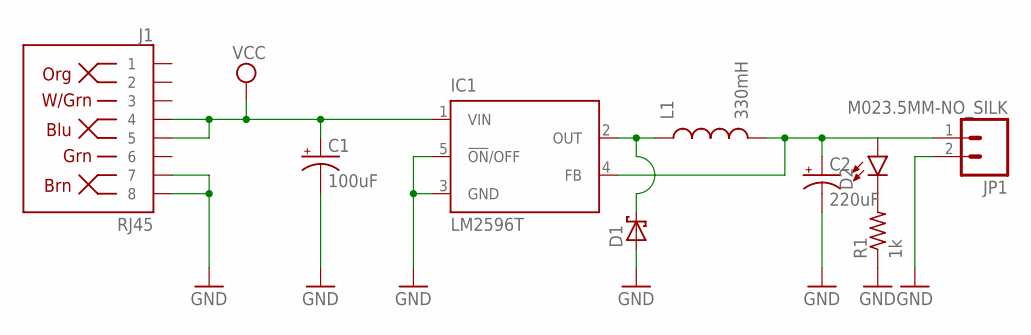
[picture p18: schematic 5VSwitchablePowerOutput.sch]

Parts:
C1: 100uF; E5-13
C2: 220uF; E3,5-10
D1: SCHOTTKY-DIODECB417-15; CB417-15
D2: LED5MM; LED_5MM
IC1: LM2596T; T05D
J1: RJ45; RJ45-8
JP1: M023.5MM-NO_SILK; SCREWTERMINAL-3.5MM-2-NS
L1: 330mH; RLB0912
R1: 1k; 0204/7

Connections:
GND: C1.-, C2.-, D1.A, IC1.3 (GND), IC1.5 (!ON!/OFF), J1.7, J1.8, JP1.2, R1.1
unnamed: D1.C, IC1.2 (OUT), L1.1
unnamed: C2.+, D2.A, IC1.4 (FB), JP1.1, L1.2
unnamed: D2.K (C), R1.2
VCC: C1.+, IC1.1 (VIN), J1.4, J1.5


Board: 2 copper layers, 33.0 x 57.1 mm, 9 parts (0 on the bottom side), 5 nets.

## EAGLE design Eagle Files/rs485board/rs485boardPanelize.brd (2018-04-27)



Board: 2 copper layers, 139.6 x 155.8 mm, 384 parts (8 on the bottom side), 240 nets.

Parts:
C1, C1X12, C1X21, C1X22, C3, C3X12, C3X21, C3X22, C4, C4X12, C4X21, C4X22, C5, C5X12, C5X21, C5X22, C7, C7X12, C7X21, C7X22, C8, C8X12, C8X21, C8X22, C9, C9X12, C9X21, C9X22, C10, C10X12, C10X21, C10X22, C14, C14X12, C14X21, C14X22, C15, C15X12, C15X21, C15X22, C16, C16X12, C16X21, C16X22, C17, C17X12, C17X21, C17X22, C18, C18X12, C18X21, C18X22, C19, C19X12, C19X21, C19X22, C20, C20X12, C20X21, C20X22, C21, C21X12, C21X21, C21X22, C22, C22X12, C22X21, C22X22, C23, C23X12, C23X21, C23X22, C24, C24X12, C24X21, C24X22, C25, C25X12, C25X21, C25X22, C26, C26X12, C26X21, C26X22: 0.1uF; C0805K
C2, C2X12, C2X21, C2X22, C6, C6X12, C6X21, C6X22, C12, C12X12, C12X21, C12X22, C38, C38X12, C38X21, C38X22: 10uF; C0805K
C13, C13X12, C13X21, C13X22, C27, C27X12, C27X21, C27X22, C28, C28X12, C28X21, C28X22, C29, C29X12, C29X21, C29X22, C30, C30X12, C30X21, C30X22, C31, C31X12, C31X21, C31X22, C32, C32X12, C32X21, C32X22, C33, C33X12, C33X21, C33X22, C34, C34X12, C34X21, C34X22, C35, C35X12, C35X21, C35X22: 1uF 100V; 1206
C36, C36X12, C36X21, C36X22: 150pF; C0805K
D1, D1X12, D1X21, D1X22, D2, D2X12, D2X21, D2X22, D3, D3X12, D3X21, D3X22, D4, D4X12, D4X21, D4X22, D5, D5X12, D5X21, D5X22, D6, D6X12, D6X21, D6X22: 5819; SOD-123
D7, D7X12, D7X21, D7X22, D8, D8X12, D8X21, D8X22, D9, D9X12, D9X21, D9X22, D10, D10X12, D10X21, D10X22, D11, D11X12, D11X21, D11X22, D12, D12X12, D12X21, D12X22, D13, D13X12, D13X21, D13X22, D14, D14X12, D14X21, D14X22, D15, D15X12, D15X21, D15X22, D16, D16X12, D16X21, D16X22, D17, D17X12, D17X21, D17X22, D18, D18X12, D18X21, D18X22: WS2812B
D20, D20X12, D20X21, D20X22: B280-13-F; DO214AA
E$1, E$2, E$3, E$4: FIDUCIAL-1X2
IC1, IC1X12, IC1X21, IC1X22: XC6206P332MR; SOT23
IC2, IC2X12, IC2X21, IC2X22: MP2562; SO08
J1, J1X12, J1X21, J1X22: AVR_SPI_PROG_3X2PTH; 2X3
J2, J2X12, J2X21, J2X22: RA 6Pin SMD; 1X06-SMD_RA_MALE
J3, J3X12, J3X21, J3X22, J4, J4X12, J4X21, J4X22, J5, J5X12, J5X21, J5X22, J6, J6X12, J6X21, J6X22: 1X01
L1, L1X12, L1X21, L1X22: 15uH; SLF12575
PAD1, PAD1X12, PAD1X21, PAD1X22, PAD2, PAD2X12, PAD2X21, PAD2X22, PAD3, PAD3X12, PAD3X21, PAD3X22, PAD4, PAD4X12, PAD4X21, PAD4X22, PAD5, PAD5X12, PAD5X21, PAD5X22: 1,6/0,8
Q1, Q1X12, Q1X21, Q1X22, Q2, Q2X12, Q2X21, Q2X22, Q3, Q3X12, Q3X21, Q3X22: CJ3404; SOT23-3
R1, R1X12, R1X21, R1X22, R5, R5X12, R5X21, R5X22, R6, R6X12, R6X21, R6X22, R7, R7X12, R7X21, R7X22, R14, R14X12, R14X21, R14X22: 10K; R0805
R2, R2X12, R2X21, R2X22, R3, R3X12, R3X21, R3X22, R4, R4X12, R4X21, R4X22: DNP; R0805
R8, R8X12, R8X21, R8X22: 100K; R0805
R9, R9X12, R9X21, R9X22: 210K; R0805
R10, R10X12, R10X21, R10X22: 40.2k; R0805
R11, R11X12, R11X21, R11X22: 120; R0805
R12, R12X12, R12X21, R12X22, R13, R13X12, R13X21, R13X22: 1K; R0805
R15, R15X12, R15X21, R15X22: 17.4K; R0805
R16, R16X12, R16X21, R16X22: 200K; R0805
R17, R17X12, R17X21, R17X22: 158K; R0805
U1, U1X12, U1X21, U1X22: ATMEGA328P_TQFP; TQFP32-08
U2, U2X12, U2X21, U2X22: LIS3DH; LGA-16-3X3
U3, U3X12, U3X21, U3X22: SP485; SO08
X1, X1X12, X1X21, X1X22, X3, X3X12, X3X21, X3X22: RJ45-8P8C-8L-B; RJ45-SHIELD-DS1128-S80BP
Y1, Y1X12, Y1X21, Y1X22: 16MHz; RESONATOR-SMD-3.2X1.3

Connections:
+3V3: C6.1, C7.1, C9.1, IC1.2, R5.2, R6.2, R7.2, U2.1, U2.14
+3V3X12: C6X12.1, C7X12.1, C9X12.1, IC1X12.2, R5X12.2, R6X12.2, R7X12.2, U2X12.1, U2X12.14
+3V3X21: C6X21.1, C7X21.1, C9X21.1, IC1X21.2, R5X21.2, R6X21.2, R7X21.2, U2X21.1, U2X21.14
+3V3X22: C6X22.1, C7X22.1, C9X22.1, IC1X22.2, R5X22.2, R6X22.2, R7X22.2, U2X22.1, U2X22.14
+5V: C2.1, C3.1, C4.1, C8.1, C12.1, C14.1, C15.1, C16.1, C17.1, C18.1, C19.1, C20.1, C21.1, C22.1, C23.1, C24.1, C25.1, C26.1, C38.1, D7.1, D8.1, D9.1, D10.1, D11.1, D12.1, D13.1, D14.1, D15.1, D16.1, D17.1, D18.1, IC1.3, J1.2, J2.4, J6.1, L1.P$2, R1.2, R9.2, R14.2, U1.4, U1.6, U1.18, U3.8
+5VX12: C2X12.1, C3X12.1, C4X12.1, C8X12.1, C12X12.1, C14X12.1, C15X12.1, C16X12.1, C17X12.1, C18X12.1, C19X12.1, C20X12.1, C21X12.1, C22X12.1, C23X12.1, C24X12.1, C25X12.1, C26X12.1, C38X12.1, D7X12.1, D8X12.1, D9X12.1, D10X12.1, D11X12.1, D12X12.1, D13X12.1, D14X12.1, D15X12.1, D16X12.1, D17X12.1, D18X12.1, IC1X12.3, J1X12.2, J2X12.4, J6X12.1, L1X12.P$2, R1X12.2, R9X12.2, R14X12.2, U1X12.4, U1X12.6, U1X12.18, U3X12.8
+5VX21: C2X21.1, C3X21.1, C4X21.1, C8X21.1, C12X21.1, C14X21.1, C15X21.1, C16X21.1, C17X21.1, C18X21.1, C19X21.1, C20X21.1, C21X21.1, C22X21.1, C23X21.1, C24X21.1, C25X21.1, C26X21.1, C38X21.1, D7X21.1, D8X21.1, D9X21.1, D10X21.1, D11X21.1, D12X21.1, D13X21.1, D14X21.1, D15X21.1, D16X21.1, D17X21.1, D18X21.1, IC1X21.3, J1X21.2, J2X21.4, J6X21.1, L1X21.P$2, R1X21.2, R9X21.2, R14X21.2, U1X21.4, U1X21.6, U1X21.18, U3X21.8
+5VX22: C2X22.1, C3X22.1, C4X22.1, C8X22.1, C12X22.1, C14X22.1, C15X22.1, C16X22.1, C17X22.1, C18X22.1, C19X22.1, C20X22.1, C21X22.1, C22X22.1, C23X22.1, C24X22.1, C25X22.1, C26X22.1, C38X22.1, D7X22.1, D8X22.1, D9X22.1, D10X22.1, D11X22.1, D12X22.1, D13X22.1, D14X22.1, D15X22.1, D16X22.1, D17X22.1, D18X22.1, IC1X22.3, J1X22.2, J2X22.4, J6X22.1, L1X22.P$2, R1X22.2, R9X22.2, R14X22.2, U1X22.4, U1X22.6, U1X22.18, U3X22.8
+24V: C13.1, C27.1, C28.1, C29.1, C30.1, C31.1, C32.1, C33.1, C34.1, C35.1, IC2.7, R8.2, X1.4, X1.5, X3.4, X3.5
+24VX12: C13X12.1, C27X12.1, C28X12.1, C29X12.1, C30X12.1, C31X12.1, C32X12.1, C33X12.1, C34X12.1, C35X12.1, IC2X12.7, R8X12.2, X1X12.4, X1X12.5, X3X12.4, X3X12.5
+24VX21: C13X21.1, C27X21.1, C28X21.1, C29X21.1, C30X21.1, C31X21.1, C32X21.1, C33X21.1, C34X21.1, C35X21.1, IC2X21.7, R8X21.2, X1X21.4, X1X21.5, X3X21.4, X3X21.5
+24VX22: C13X22.1, C27X22.1, C28X22.1, C29X22.1, C30X22.1, C31X22.1, C32X22.1, C33X22.1, C34X22.1, C35X22.1, IC2X22.7, R8X22.2, X1X22.4, X1X22.5, X3X22.4, X3X22.5
A3: D7.4, U1.26
A3X12: D7X12.4, U1X12.26
A3X21: D7X21.4, U1X21.26
A3X22: D7X22.4, U1X22.26
A4: PAD3.1, U1.27
A4X12: PAD3X12.1, U1X12.27
A4X21: PAD3X21.1, U1X21.27
A4X22: PAD3X22.1, U1X22.27
A5: PAD4.1, U1.28
A5X12: PAD4X12.1, U1X12.28
A5X21: PAD4X21.1, U1X21.28
A5X22: PAD4X22.1, U1X22.28
AREF: C5.2, U1.20
AREFX12: C5X12.2, U1X12.20
AREFX21: C5X21.2, U1X21.20
AREFX22: C5X22.2, U1X22.20
BST: C10.1, IC2.8
BSTX12: C10X12.1, IC2X12.8
BSTX21: C10X21.1, IC2X21.8
BSTX22: C10X22.1, IC2X22.8
COMP: C36.1, IC2.3
COMPX12: C36X12.1, IC2X12.3
COMPX21: C36X21.1, IC2X21.3
COMPX22: C36X22.1, IC2X22.3
D2: D5.C, U1.32
D2X12: D5X12.C, U1X12.32
D2X21: D5X21.C, U1X21.32
D2X22: D5X22.C, U1X22.32
D3: D6.C, U1.1
D3X12: D6X12.C, U1X12.1
D3X21: D6X21.C, U1X21.1
D3X22: D6X22.C, U1X22.1
D5: Q3.1, U1.9
D5X12: Q3X12.1, U1X12.9
D5X21: Q3X21.1, U1X21.9
D5X22: Q3X22.1, U1X22.9
D6: Q2.1, U1.10
D6X12: Q2X12.1, U1X12.10
D6X21: Q2X21.1, U1X21.10
D6X22: Q2X22.1, U1X22.10
D7: PAD1.1, U1.11
D7X12: PAD1X12.1, U1X12.11
D7X21: PAD1X21.1, U1X21.11
D7X22: PAD1X22.1, U1X22.11
D8: PAD2.1, U1.12
D8X12: PAD2X12.1, U1X12.12
D8X21: PAD2X21.1, U1X21.12
D8X22: PAD2X22.1, U1X22.12
D9: Q1.1, U1.13
D9X12: Q1X12.1, U1X12.13
D9X21: Q1X21.1, U1X21.13
D9X22: Q1X22.1, U1X22.13
DIR: U1.2, U3.2, U3.3
DIRX12: U1X12.2, U3X12.2, U3X12.3
DIRX21: U1X21.2, U3X21.2, U3X21.3
DIRX22: U1X22.2, U3X22.2, U3X22.3
EN: IC2.2, R8.1, R15.2
ENX12: IC2X12.2, R8X12.1, R15X12.2
ENX21: IC2X21.2, R8X21.1, R15X21.2
ENX22: IC2X22.2, R8X22.1, R15X22.2
FB: IC2.4, R9.1, R10.2
FBX12: IC2X12.4, R9X12.1, R10X12.2
FBX21: IC2X21.4, R9X21.1, R10X21.2
FBX22: IC2X22.4, R9X22.1, R10X22.2
FREQ: IC2.6, R16.2
FREQX12: IC2X12.6, R16X12.2
FREQX21: IC2X21.6, R16X21.2
FREQX22: IC2X22.6, R16X22.2
GND: C2.2, C3.2, C4.2, C5.1, C6.2, C7.2, C8.2, C9.2, C12.2, C13.2, C14.2, C15.2, C16.2, C17.2, C18.2, C19.2, C20.2, C21.2, C22.2, C23.2, C24.2, C25.2, C26.2, C27.2, C28.2, C29.2, C30.2, C31.2, C32.2, C33.2, C34.2, C35.2, C38.2, D7.3, D8.3, D9.3, D10.3, D11.3, D12.3, D13.3, D14.3, D15.3, D16.3, D17.3, D18.3, D20.A, IC1.1, IC2.5, J1.6, J2.6, PAD5.1, Q1.2, Q2.2, Q3.2, R10.1, R15.1, R16.1, R17.1, U1.3, U1.5, U1.21, U2.5, U2.10, U2.12, U3.5, X1.3, X1.6, X1.7, X1.8, X3.3, X3.6, X3.7, X3.8, Y1.2
GNDX12: C2X12.2, C3X12.2, C4X12.2, C5X12.1, C6X12.2, C7X12.2, C8X12.2, C9X12.2, C12X12.2, C13X12.2, C14X12.2, C15X12.2, C16X12.2, C17X12.2, C18X12.2, C19X12.2, C20X12.2, C21X12.2, C22X12.2, C23X12.2, C24X12.2, C25X12.2, C26X12.2, C27X12.2, C28X12.2, C29X12.2, C30X12.2, C31X12.2, C32X12.2, C33X12.2, C34X12.2, C35X12.2, C38X12.2, D7X12.3, D8X12.3, D9X12.3, D10X12.3, D11X12.3, D12X12.3, D13X12.3, D14X12.3, D15X12.3, D16X12.3, D17X12.3, D18X12.3, D20X12.A, IC1X12.1, IC2X12.5, J1X12.6, J2X12.6, PAD5X12.1, Q1X12.2, Q2X12.2, Q3X12.2, R10X12.1, R15X12.1, R16X12.1, R17X12.1, U1X12.3, U1X12.5, U1X12.21, U2X12.5, U2X12.10, U2X12.12, U3X12.5, X1X12.3, X1X12.6, X1X12.7, X1X12.8, X3X12.3, X3X12.6, X3X12.7, X3X12.8, Y1X12.2
GNDX21: C2X21.2, C3X21.2, C4X21.2, C5X21.1, C6X21.2, C7X21.2, C8X21.2, C9X21.2, C12X21.2, C13X21.2, C14X21.2, C15X21.2, C16X21.2, C17X21.2, C18X21.2, C19X21.2, C20X21.2, C21X21.2, C22X21.2, C23X21.2, C24X21.2, C25X21.2, C26X21.2, C27X21.2, C28X21.2, C29X21.2, C30X21.2, C31X21.2, C32X21.2, C33X21.2, C34X21.2, C35X21.2, C38X21.2, D7X21.3, D8X21.3, D9X21.3, D10X21.3, D11X21.3, D12X21.3, D13X21.3, D14X21.3, D15X21.3, D16X21.3, D17X21.3, D18X21.3, D20X21.A, IC1X21.1, IC2X21.5, J1X21.6, J2X21.6, PAD5X21.1, Q1X21.2, Q2X21.2, Q3X21.2, R10X21.1, R15X21.1, R16X21.1, R17X21.1, U1X21.3, U1X21.5, U1X21.21, U2X21.5, U2X21.10, U2X21.12, U3X21.5, X1X21.3, X1X21.6, X1X21.7, X1X21.8, X3X21.3, X3X21.6, X3X21.7, X3X21.8, Y1X21.2
GNDX22: C2X22.2, C3X22.2, C4X22.2, C5X22.1, C6X22.2, C7X22.2, C8X22.2, C9X22.2, C12X22.2, C13X22.2, C14X22.2, C15X22.2, C16X22.2, C17X22.2, C18X22.2, C19X22.2, C20X22.2, C21X22.2, C22X22.2, C23X22.2, C24X22.2, C25X22.2, C26X22.2, C27X22.2, C28X22.2, C29X22.2, C30X22.2, C31X22.2, C32X22.2, C33X22.2, C34X22.2, C35X22.2, C38X22.2, D7X22.3, D8X22.3, D9X22.3, D10X22.3, D11X22.3, D12X22.3, D13X22.3, D14X22.3, D15X22.3, D16X22.3, D17X22.3, D18X22.3, D20X22.A, IC1X22.1, IC2X22.5, J1X22.6, J2X22.6, PAD5X22.1, Q1X22.2, Q2X22.2, Q3X22.2, R10X22.1, R15X22.1, R16X22.1, R17X22.1, U1X22.3, U1X22.5, U1X22.21, U2X22.5, U2X22.10, U2X22.12, U3X22.5, X1X22.3, X1X22.6, X1X22.7, X1X22.8, X3X22.3, X3X22.6, X3X22.7, X3X22.8, Y1X22.2
INT1: D5.A, U2.11
INT1X12: D5X12.A, U2X12.11
INT1X21: D5X21.A, U2X21.11
INT1X22: D5X22.A, U2X22.11
INT2: D6.A, U2.9
INT2X12: D6X12.A, U2X12.9
INT2X21: D6X21.A, U2X21.9
INT2X22: D6X22.A, U2X22.9
MISO: D3.C, J1.1, U1.16
MISOX12: D3X12.C, J1X12.1, U1X12.16
MISOX21: D3X21.C, J1X21.1, U1X21.16
MISOX22: D3X22.C, J1X22.1, U1X22.16
MISO_3.3V: D3.A, U2.7
MISO_3.3VX12: D3X12.A, U2X12.7
MISO_3.3VX21: D3X21.A, U2X21.7
MISO_3.3VX22: D3X22.A, U2X22.7
MOSI: D2.C, J1.4, U1.15
MOSIX12: D2X12.C, J1X12.4, U1X12.15
MOSIX21: D2X21.C, J1X21.4, U1X21.15
MOSIX22: D2X22.C, J1X22.4, U1X22.15
MOSI_3.3V: D2.A, R6.1, U2.6
MOSI_3.3VX12: D2X12.A, R6X12.1, U2X12.6
MOSI_3.3VX21: D2X21.A, R6X21.1, U2X21.6
MOSI_3.3VX22: D2X22.A, R6X22.1, U2X22.6
unnamed: Q1.3, R2.1
unnamed: Q1X12.3, R2X12.1
unnamed: Q1X21.3, R2X21.1
unnamed: Q1X22.3, R2X22.1
unnamed: D7.2, D8.4
unnamed: D7X12.2, D8X12.4
unnamed: D7X21.2, D8X21.4
unnamed: D7X22.2, D8X22.4
unnamed: D8.2, D9.4
unnamed: D8X12.2, D9X12.4
unnamed: D8X21.2, D9X21.4
unnamed: D8X22.2, D9X22.4
unnamed: J3.1, R2.2
unnamed: J3X12.1, R2X12.2
unnamed: J3X21.1, R2X21.2
unnamed: J3X22.1, R2X22.2
unnamed: Q2.3, R3.1
unnamed: Q2X12.3, R3X12.1
unnamed: Q2X21.3, R3X21.1
unnamed: Q2X22.3, R3X22.1
unnamed: J4.1, R3.2
unnamed: J4X12.1, R3X12.2
unnamed: J4X21.1, R3X21.2
unnamed: J4X22.1, R3X22.2
unnamed: Q3.3, R4.1
unnamed: Q3X12.3, R4X12.1
unnamed: Q3X21.3, R4X21.1
unnamed: Q3X22.3, R4X22.1
unnamed: J5.1, R4.2
unnamed: J5X12.1, R4X12.2
unnamed: J5X21.1, R4X21.2
unnamed: J5X22.1, R4X22.2
unnamed: D9.2, D10.4
unnamed: D9X12.2, D10X12.4
unnamed: D9X21.2, D10X21.4
unnamed: D9X22.2, D10X22.4
unnamed: D10.2, D11.4
unnamed: D10X12.2, D11X12.4
unnamed: D10X21.2, D11X21.4
unnamed: D10X22.2, D11X22.4
unnamed: D11.2, D12.4
unnamed: D11X12.2, D12X12.4
unnamed: D11X21.2, D12X21.4
unnamed: D11X22.2, D12X22.4
unnamed: D12.2, D13.4
unnamed: D12X12.2, D13X12.4
unnamed: D12X21.2, D13X21.4
unnamed: D12X22.2, D13X22.4
unnamed: D13.2, D14.4
unnamed: D13X12.2, D14X12.4
unnamed: D13X21.2, D14X21.4
unnamed: D13X22.2, D14X22.4
unnamed: D14.2, D15.4
unnamed: D14X12.2, D15X12.4
unnamed: D14X21.2, D15X21.4
unnamed: D14X22.2, D15X22.4
unnamed: D15.2, D16.4
unnamed: D15X12.2, D16X12.4
unnamed: D15X21.2, D16X21.4
unnamed: D15X22.2, D16X22.4
unnamed: D16.2, D17.4
unnamed: D16X12.2, D17X12.4
unnamed: D16X21.2, D17X21.4
unnamed: D16X22.2, D17X22.4
unnamed: D17.2, D18.4
unnamed: D17X12.2, D18X12.4
unnamed: D17X21.2, D18X21.4
unnamed: D17X22.2, D18X22.4
unnamed: C36.2, R17.2
unnamed: C36X12.2, R17X12.2
unnamed: C36X21.2, R17X21.2
unnamed: C36X22.2, R17X22.2
unnamed: R12.2, U3.1
unnamed: R12X12.2, U3X12.1
unnamed: R12X21.2, U3X21.1
unnamed: R12X22.2, U3X22.1
unnamed: R13.2, U3.4
unnamed: R13X12.2, U3X12.4
unnamed: R13X21.2, U3X21.4
unnamed: R13X22.2, U3X22.4
RESET: C1.2, J1.5, R1.1, U1.29
RESETX12: C1X12.2, J1X12.5, R1X12.1, U1X12.29
RESETX21: C1X21.2, J1X21.5, R1X21.1, U1X21.29
RESETX22: C1X22.2, J1X22.5, R1X22.1, U1X22.29
RESET_EXT: C1.1, J2.1
RESET_EXTX12: C1X12.1, J2X12.1
RESET_EXTX21: C1X21.1, J2X21.1
RESET_EXTX22: C1X22.1, J2X22.1
RS485A: R11.1, U3.6, X1.2, X3.2
RS485AX12: R11X12.1, U3X12.6, X1X12.2, X3X12.2
RS485AX21: R11X21.1, U3X21.6, X1X21.2, X3X21.2
RS485AX22: R11X22.1, U3X22.6, X1X22.2, X3X22.2
RS485B: R11.2, U3.7, X1.1, X3.1
RS485BX12: R11X12.2, U3X12.7, X1X12.1, X3X12.1
RS485BX21: R11X21.2, U3X21.7, X1X21.1, X3X21.1
RS485BX22: R11X22.2, U3X22.7, X1X22.1, X3X22.1
RX: J2.3, R12.1, R14.1, U1.30
RXX12: J2X12.3, R12X12.1, R14X12.1, U1X12.30
RXX21: J2X21.3, R12X21.1, R14X21.1, U1X21.30
RXX22: J2X22.3, R12X22.1, R14X22.1, U1X22.30
SCK: D4.C, J1.3, U1.17
SCKX12: D4X12.C, J1X12.3, U1X12.17
SCKX21: D4X21.C, J1X21.3, U1X21.17
SCKX22: D4X22.C, J1X22.3, U1X22.17
SCK_3.3V: D4.A, R7.1, U2.4
SCK_3.3VX12: D4X12.A, R7X12.1, U2X12.4
SCK_3.3VX21: D4X21.A, R7X21.1, U2X21.4
SCK_3.3VX22: D4X22.A, R7X22.1, U2X22.4
SS: D1.C, U1.14
SSX12: D1X12.C, U1X12.14
SSX21: D1X21.C, U1X21.14
SSX22: D1X22.C, U1X22.14
SS_3.3V: D1.A, R5.1, U2.8
SS_3.3VX12: D1X12.A, R5X12.1, U2X12.8
SS_3.3VX21: D1X21.A, R5X21.1, U2X21.8
SS_3.3VX22: D1X22.A, R5X22.1, U2X22.8
SW: C10.2, D20.C, IC2.1, L1.P$1
SWX12: C10X12.2, D20X12.C, IC2X12.1, L1X12.P$1
SWX21: C10X21.2, D20X21.C, IC2X21.1, L1X21.P$1
SWX22: C10X22.2, D20X22.C, IC2X22.1, L1X22.P$1
TX: J2.2, R13.1, U1.31
TXX12: J2X12.2, R13X12.1, U1X12.31
TXX21: J2X21.2, R13X21.1, U1X21.31
TXX22: J2X22.2, R13X22.1, U1X22.31
XTAL1: U1.7, Y1.1
XTAL1X12: U1X12.7, Y1X12.1
XTAL1X21: U1X21.7, Y1X21.1
XTAL1X22: U1X22.7, Y1X22.1
XTAL2: U1.8, Y1.3
XTAL2X12: U1X12.8, Y1X12.3
XTAL2X21: U1X21.8, Y1X21.3
XTAL2X22: U1X22.8, Y1X22.3

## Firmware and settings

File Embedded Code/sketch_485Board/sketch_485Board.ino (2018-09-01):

#include <SPI.h>
#include <EEPROM.h>
#include <avr/power.h>
#include "Simple_LIS3DH.h"
#include "Simple_NeoPixel.h"

#define LED_PIN        A3

#define LIS3DH_REG_WHOAMI        0x0F

Simple_NeoPixel pixels = Simple_NeoPixel(LED_PIN, NEO_GRB + NEO_KHZ800);
//Simple_NeoPixel pixels = Simple_NeoPixel(LED_PIN, NEO_GRBW + NEO_KHZ800);
Simple_LIS3DH lis = Simple_LIS3DH(10);

char inputString[128] = {'\0'};       // a String to hold incoming data
unsigned char inputStringIndex = 0;
boolean stringComplete = false;  // whether the string is complete

bool powerUPLedFinished = false;

bool streamRawData = false;
unsigned long streamRawDataBeginTime = 0;
signed long streamTime = 10 * 1000;

unsigned char boardID = 0;


#define ACC_EVENT_STABLE_CENTER  0
#define ACC_EVENT_STABLE_TILTED  1
#define ACC_EVENT_UNSTABLE       2

unsigned char accelerometerEvent = ACC_EVENT_STABLE_CENTER;

int envelopeRate = 32;
int envelopeThreshold = 768;
int centerThreshold = 384;
int offsetX = 0;
int offsetY = 0;

uint8_t fadeColorR, fadeColorG, fadeColorB;
uint8_t startColorR, startColorG, startColorB;
unsigned long fadeBeginTime = 0;
unsigned long fadeDuration = 0;
bool fading = false;

uint8_t currentColorR = 0, currentColorG = 0, currentColorB = 0;

void setup() {

  pinMode(4, OUTPUT); //485DIR
  digitalWrite(4, LOW);

  Serial.begin(115200);

  boardID = EEPROM.read(0);

  char compile_date[] = __DATE__ " " __TIME__;

  Serial.print(F("\nCompiled on: "));
  Serial.println(compile_date);

  Serial.print(F("RS485 Address: "));
  Serial.println(boardID);

  pixels.begin(); // This initializes the NeoPixel library.

  if (! lis.begin()) {
    Serial.println(F("Couldnt start"));
    while (1);
  }
  Serial.println(F("LIS3DH found!"));

  lis.setRange(LIS3DH_RANGE_4_G);   // 2, 4, 8 or 16 G!

  Serial.print(F("Range = ")); Serial.print(2 << lis.getRange());
  Serial.println(F("G"));

  lis.setupFifo();

  pinMode(7, OUTPUT); //debug
  pinMode(8, OUTPUT); //debug
}



void loop() {
  unsigned long currentMillis = millis();

  if (!powerUPLedFinished) {
    static unsigned long LEDPreviousMillis = 0;
    static int stepCount = 0;
    if (currentMillis - LEDPreviousMillis >= 10) {
      pixels.clear();
      if (stepCount < 64) {
        uint8_t testBrightness = stepCount;
        for (int i = 0; i < NUMPIXELS; i += 2) {
          pixels.setPixelColor(i, testBrightness, testBrightness, testBrightness);
        }
      } else if (stepCount < 64 * 2) {
        uint8_t testBrightness1 = 127 - stepCount;
        uint8_t testBrightness2 = 63 - testBrightness1;
        for (int i = 0; i < NUMPIXELS; i += 2) {
          pixels.setPixelColor(i, testBrightness1, testBrightness1, testBrightness1);
          pixels.setPixelColor(i + 1, testBrightness2, testBrightness2, testBrightness2);
        }
      } else if (stepCount < 64 * 3) {
        uint8_t testBrightness3 = 191 - stepCount;
        for (int i = 0; i < NUMPIXELS; i += 2) {
          pixels.setPixelColor(i + 1, testBrightness3, testBrightness3, testBrightness3);
        }
      }  else {
        powerUPLedFinished = true;
      }
      pixels.show(); // This sends the updated pixel color to the hardware.
      stepCount++;
      LEDPreviousMillis = currentMillis;
    }
  }

  static unsigned long sensorPreviousMillis = 0;
  if (currentMillis - sensorPreviousMillis >= 20) {
    bool fifoError = false;

    uint8_t fifoStatus = lis.fifoGetStatus();
    fifoError = ((fifoStatus & 0x40) != 0);//OVRN_FIFO
    while ( (fifoStatus & 0b11111 ) > 0 ) {
      lis.read();      // get X Y and Z data at once
      lis.x -= offsetX;
      lis.y -= offsetY;

      accelerometerEvent = accelerometerEventProcess(lis.x, lis.y);
      // Then print out the raw data

      if (streamRawData) {
        char buf[20];
        char* bufPtr = buf;
        *bufPtr = 'S';
        *bufPtr++;
        bufPtr = ucharToHex2_no_end(boardID, bufPtr);
        bufPtr = uintToHex4_no_end(lis.x, bufPtr);
        bufPtr = uintToHex4_no_end(lis.y, bufPtr);
        bufPtr = uintToHex4(lis.z, bufPtr);
        *bufPtr++ = '\n';
        *bufPtr++ = '\0';
        digitalWrite(4, HIGH);
        Serial.print(buf);
      }
      fifoStatus = lis.fifoGetStatus();
    }
    /*if (accelerometerEvent == ACC_EVENT_UNSTABLE) setLEDcolor(64, 0, 0);
      else if (accelerometerEvent == ACC_EVENT_STABLE_CENTER) setLEDcolor(0, 64, 0);
      else if (accelerometerEvent == ACC_EVENT_STABLE_TILTED) setLEDcolor(0, 0, 64);*/
    Serial.flush();
    digitalWrite(4, LOW);


    if (fifoError) {
      Serial.println(F("FIFO ERR"));
      lis.resetFifo();
    }

    sensorPreviousMillis = currentMillis;
  }

  if (fading && powerUPLedFinished) {
    unsigned int elaspedTime = millis () - fadeBeginTime;
    unsigned char r, g, b;
    if (elaspedTime >= fadeDuration) {
      fading = false;
      r = fadeColorR; g = fadeColorG; b = fadeColorB;
    } else {
      r = map(elaspedTime, 0, fadeDuration, startColorR, fadeColorR);
      g = map(elaspedTime, 0, fadeDuration, startColorG, fadeColorG);
      b = map(elaspedTime, 0, fadeDuration, startColorB, fadeColorB);
    }
    setRingColor(r, g, b);
  }


  if (streamRawData) {
    if ((signed long)(currentMillis - streamRawDataBeginTime) >= streamTime) {
      streamRawData = false;
    }
  }

  if (stringComplete) {
    uint8_t id = hexToUchar2(&inputString[1]);
    uint8_t stringLength = strlen(inputString);
    if (inputString[0] == 'S' && stringLength == 5  ) { //stream mode
      if (id == boardID) {
        streamRawDataBeginTime = millis();
        uint8_t inputTime = hexToUchar2(&inputString[3]);
        streamTime = ((unsigned int)inputTime) * inputTime * 100ul;
        streamRawData = true;
      }
    } else if (inputString[0] == 'L' && stringLength == 9 ) { //set light color
      if (id == boardID) {  //L01080808
        uint8_t r = hexToUchar2(&inputString[3]);
        uint8_t g = hexToUchar2(&inputString[5]);
        uint8_t b = hexToUchar2(&inputString[7]);
        if (powerUPLedFinished) {
          setRingColor(r, g, b);
        }
      }
    } else if (inputString[0] == 'F' && stringLength == 13 ) { //Fade light color
      if (id == boardID) {  //F010808080064
        fadeColorR = hexToUchar2(&inputString[3]);
        fadeColorG = hexToUchar2(&inputString[5]);
        fadeColorB = hexToUchar2(&inputString[7]);
        startColorR = currentColorR;
        startColorG = currentColorG;
        startColorB = currentColorB;
        fadeDuration = hexToInt16(&inputString[9]);
        fadeBeginTime = millis();
        fading = true;
      }
    } else if (inputString[0] == 'E' && stringLength == 3) {  //report back current value
      if (id == boardID) {
        char buf[16];
        char* bufPtr = buf;
        *bufPtr = 'E';
        *bufPtr++;
        bufPtr = ucharToHex2_no_end(boardID, bufPtr);
        bufPtr = ucharToHex2_no_end(accelerometerEvent, bufPtr);
        bufPtr = uintToHex4_no_end(lis.x, bufPtr);
        bufPtr = uintToHex4(lis.y, bufPtr);
        *bufPtr++ = '\n';
        *bufPtr++ = '\0';
        digitalWrite(4, HIGH);
        Serial.print(buf);
        Serial.flush();
        digitalWrite(4, LOW);
      }
    } else if (inputString[0] == 'P' && stringLength == (3 + 12)) { //set parameters
      if (id == boardID) {
        envelopeRate = hexToInt16(&inputString[3]);
        envelopeThreshold = hexToInt16(&inputString[7]);
        centerThreshold = hexToInt16(&inputString[11]);
      }
    } else if (inputString[0] == 'O' && stringLength == (3 + 8)) { //set offset
      if (id == boardID) {
        offsetX = hexToInt16(&inputString[3]);
        offsetY = hexToInt16(&inputString[7]);
      }
    }

    inputStringIndex = 0;
    inputString[0] = '\0';

    stringComplete = false;
  }
  while (Serial.available()) {
    // get the new byte:
    char inChar = (char)Serial.read();
    if (inChar == '\n' || inChar == '\r') {
      stringComplete = true;
      inputString[inputStringIndex] = '\0';
      inputStringIndex++;
      break;
    } else {
      if (inputStringIndex < 63) {
        inputString[inputStringIndex] = inChar;
        inputStringIndex++;
      }
    }
  }

}

void setRingColor(uint8_t r, uint8_t g, uint8_t b) {
  currentColorR = r; currentColorG = g; currentColorB = b;
  for (int i = 0; i < NUMPIXELS; i++) {
    pixels.setPixelColor(i, r, g, b);
  }
  pixels.show();
}

unsigned char accelerometerEventProcess(int16_t x, int16_t y) {
  static unsigned char state = ACC_EVENT_UNSTABLE;
  static int axisEvenlopXTop = 0, axisEvenlopXBtm = 0;
  static int axisEvenlopYTop = 0, axisEvenlopYBtm = 0;
  static unsigned char stableCenterAccu = 0;
  static unsigned char stableTiltAccu = 0;


  axisEvenlopXTop -= envelopeRate;
  if (axisEvenlopXTop < x) axisEvenlopXTop = x;
  axisEvenlopXBtm += envelopeRate;
  if (axisEvenlopXBtm > x) axisEvenlopXBtm = x;
  axisEvenlopYTop -= envelopeRate;
  if (axisEvenlopYTop < y) axisEvenlopYTop = y;
  axisEvenlopYBtm += envelopeRate;
  if (axisEvenlopYBtm > y) axisEvenlopYBtm = y;
  int envelopMaxXY = max(axisEvenlopXTop - axisEvenlopXBtm, axisEvenlopYTop - axisEvenlopYBtm);

  switch (state) {
    case ACC_EVENT_STABLE_CENTER:
    case ACC_EVENT_STABLE_TILTED:
      if (envelopMaxXY > envelopeThreshold) {
        state = ACC_EVENT_UNSTABLE;
      }
      break;
    case ACC_EVENT_UNSTABLE:
      if (envelopMaxXY < (envelopeThreshold / 8)) {
        state = ACC_EVENT_STABLE_CENTER;
      }
      break;
  }
  int maxXY = max(abs(x), abs(y));
  if (maxXY > centerThreshold) {
    stableTiltAccu++;
    stableCenterAccu = 0;
  } else if (maxXY < centerThreshold / 2) {
    stableCenterAccu++;
    stableTiltAccu = 0;
  }

  if (state != ACC_EVENT_UNSTABLE) {
    if (stableCenterAccu >= 16) {
      stableCenterAccu = 0;
      stableTiltAccu = 0;
      state = ACC_EVENT_STABLE_CENTER;
    }
    if (stableTiltAccu >= 16) {
      stableCenterAccu = 0;
      stableTiltAccu = 0;
      state = ACC_EVENT_STABLE_TILTED;
    }
  } else {
    if (stableCenterAccu > 16)  stableCenterAccu = 16;
    if (stableTiltAccu > 16)  stableTiltAccu = 16;
  }
  return state;
}

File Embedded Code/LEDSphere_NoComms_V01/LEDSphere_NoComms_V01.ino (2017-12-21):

/*
 * LED Sphere - Without Communcations 
 * Author: Ezer Longinus
 * Date: Dec 2017
 * Version: 1.0
 * 
 * Version 1.0: This code controls a single NeoPixel LED Ring through the readings of the accelerometer.
 * 
 */

 #define VERSION "1.0"

#include <Adafruit_NeoPixel.h>
#include <Wire.h>
#include <SPI.h>
#include <Adafruit_LIS3DH.h>
#include <Adafruit_Sensor.h>

#ifdef __AVR__
  #include <avr/power.h>
#endif
 
//----------- ACCELEROMETER ----------------------//
Adafruit_LIS3DH lis = Adafruit_LIS3DH();

//Setting global values for when a "trigger/tilt" occurs
float TRIGGER_MIN_X, TRIGGER_MAX_X, TRIGGER_MIN_Y, TRIGGER_MAX_Y;
//Setting global values for when the accelerometer has settled back to it's default position.
float DEFAULT_MIN_X, DEFAULT_MAX_X, DEFAULT_MIN_Y, DEFAULT_MAX_Y;

//Defines how many readings we average from the accelerometer
#define ACC_READINGS    10

float averageX, averageY;

//This modifier is to determine how far from the inital reading will 
//we need to go before determining we have triggered an event.
#define TRIGGER_MODIFIER  3.0
//This modifier is to determine how close to the initial reading will
//we need to go before entering back into the default state.
#define DEFAULT_MODIFIER  0.2
//-----------------------------------------------//


//----------- NEO-PIXEL RING --------------------//
#define PIN             6
#define NUM_LEDS        12
#define BRIGHTNESS      255

Adafruit_NeoPixel ring = Adafruit_NeoPixel(NUM_LEDS, PIN, NEO_GRBW + NEO_KHZ800);
//-----------------------------------------------//


//----------- COLOR GLOBALS --------------------//
uint32_t prevColor = 0;
uint32_t currentColor = 0;

//Color Init.
uint8_t currentRed = 255;
uint8_t currentGrn = 255;
uint8_t currentBlu = 255;
uint8_t currentWht = 128;

int colorModifier = 1;
//-----------------------------------------------//


//----------- TIMING GLOBALS --------------------//
//Track the current time for LED timing
uint32_t currentTime = 0;

//Track the 
uint32_t switchTime = 0;
uint16_t switchThresh = 500;

//How fast are we updating the LED colors
uint8_t breathFrameRate =   10;
uint8_t interuptFrameRate = 200;
#define MAX_INTERUPT_FRAMES 255

uint16_t totalFrames = 360;
uint16_t currentFrame = 0;
//-----------------------------------------------//


//---------- ANIMATION STATES -------------------//
boolean breathState = true;
boolean armInteruptState = false;
boolean interuptState = false;
//-----------------------------------------------//


void setup() {
  Serial.begin(9600);
    
  ring.setBrightness(BRIGHTNESS);
  ring.begin();
  ring.show(); // Initialize all pixels to 'off'

  currentTime = millis();

  if (! lis.begin(0x18)) {   // change this to 0x19 for alternative i2c address
    Serial.println("Couldnt start");
    while (1);
  }
  
  lis.setRange(LIS3DH_RANGE_2_G);   // 2, 4, 8 or 16 G!

  getAccelAverages();

  //Set Min and Max Values for the trigger and default values
  getMinMaxValues();


  Serial.println("===================================");
  Serial.println("LED SPHERE TEST - NO COMMS");
  Serial.print("VERSION: ");Serial.println(VERSION);
  Serial.println("LIS3DH found!");
  Serial.print("Range = "); Serial.print(2 << lis.getRange());  
  Serial.println("G");
  Serial.print("X: ");Serial.print(TRIGGER_MIN_X);Serial.print("\t");Serial.print(TRIGGER_MAX_X);Serial.print("\t");Serial.print(DEFAULT_MIN_X);Serial.print("\t");Serial.println(DEFAULT_MAX_X);
  Serial.print("Y: ");Serial.print(TRIGGER_MIN_Y);Serial.print("\t");Serial.print(TRIGGER_MAX_Y);Serial.print("\t");Serial.print(DEFAULT_MIN_Y);Serial.print("\t");Serial.println(DEFAULT_MAX_Y);  
  Serial.println("===================================");
}

void loop() {

  getAccelAverages();


  //DEFAULT STATE
  if((millis() - currentTime > breathFrameRate)&&(breathState)){
    currentFrame = 0;
    if(currentRed >= 255){
      colorModifier = -1;
    } else if(currentRed <= 0){
      colorModifier = 1;
    }
    currentRed += colorModifier;
    currentBlu += colorModifier;
    currentColor = ring.Color(currentRed, currentGrn, currentBlu, currentWht);
    setColor(currentColor);
    currentTime = millis();
  }

  //SPHERE "IS TILTING" STATE
  if((millis() - switchTime > switchThresh)&&
    ((averageX < TRIGGER_MIN_X)||(averageX > TRIGGER_MAX_X)||
     (averageY < TRIGGER_MIN_Y)||(averageY > TRIGGER_MAX_Y))){
        setColor(ring.Color(0,255,0,0)); 
        armInteruptState = true;
        breathState = false;   
    } else if((armInteruptState)&&
      ((averageX > DEFAULT_MIN_X)&&(averageX < DEFAULT_MAX_X)&&
      (averageY > DEFAULT_MIN_Y)&&(averageY < DEFAULT_MAX_Y))) {
      
      currentRed = 0; currentGrn = 255; currentBlu = 0; currentWht = 0;
      
      interuptState = true;
      armInteruptState = false;
      switchTime = millis();
    }

  //RETURN SPHERE TO DEFAULT STATE ANIMATION
  if(interuptState){
      if((micros() - currentTime > interuptFrameRate)&&(currentFrame < MAX_INTERUPT_FRAMES)){
        currentFrame++;
        if(currentRed >= 255){
          colorModifier = 0;
        } else {
          colorModifier = 1;
        }
        currentRed += colorModifier;
        currentBlu += colorModifier;
        currentWht += colorModifier;
        currentColor = ring.Color(currentRed,currentGrn,currentBlu,(currentWht/2));
        setColor(currentColor);
        currentTime = micros();
      } else if(currentFrame >= MAX_INTERUPT_FRAMES) {
        currentRed = 255; currentGrn = 255; currentBlu = 255; currentWht = 128;
        interuptState = false;
        breathState = true;
      }
  }
}

void getMinMaxValues(){
  TRIGGER_MIN_X = averageX - TRIGGER_MODIFIER;
  TRIGGER_MAX_X = averageX + TRIGGER_MODIFIER;
  TRIGGER_MIN_Y = averageY - TRIGGER_MODIFIER;
  TRIGGER_MAX_Y = averageY + TRIGGER_MODIFIER;
  DEFAULT_MIN_X = averageX - DEFAULT_MODIFIER;
  DEFAULT_MAX_X = averageX + DEFAULT_MODIFIER;
  DEFAULT_MIN_Y = averageY - DEFAULT_MODIFIER;
  DEFAULT_MAX_Y = averageY + DEFAULT_MODIFIER;
}

void getAccelAverages(){
  sensors_event_t event; 
  lis.getEvent(&event);  
  
  for(int i=0; i<ACC_READINGS; i++){
    averageX += event.acceleration.x;
    averageY += event.acceleration.y;
  } 
  averageX /= ACC_READINGS;
  averageY /= ACC_READINGS;
}

void setColor(uint32_t c){
  for(uint16_t i=0; i<ring.numPixels(); i++){
    ring.setPixelColor(i,c);
  }
  ring.show();
}

// Returns the Red component of a 32-bit color
uint8_t Red(uint32_t color)
{
    return (color >> 24) & 0xFF;
}

// Returns the Green component of a 32-bit color
uint8_t Green(uint32_t color)
{
    return (color >> 16) & 0xFF;
}

// Returns the Blue component of a 32-bit color
uint8_t Blue(uint32_t color)
{
    return (color >> 8) & 0xFF;
}

// Returns the White component of a 32-bit color
uint8_t White(uint32_t color)
{
    return color & 0xFF;
}

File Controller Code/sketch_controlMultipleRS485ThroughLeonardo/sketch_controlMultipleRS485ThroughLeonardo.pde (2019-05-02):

import oscP5.*;
import netP5.*;
OscP5 oscP5;
NetAddress myRemoteLocation1;
NetAddress myRemoteLocation2;
import java.net.InetAddress;

boolean enableOSC=true;

String myIP = "unknown";
String partnerIP = "192.168.0.102";

long accuTime = 0;
import processing.serial.*;

Serial myPort;       

int controlBoardCount = 24;
RS485LeonardoController controlBoards[] = new RS485LeonardoController[controlBoardCount];
EffectObjects effectObjects = new EffectObjects();

PImage controlBoardImg;

void setup() {
  size(1780, 750);
  frameRate(60);
  controlBoardImg = loadImage("control_pcb.png");

  for (int i=0; i<controlBoardCount/2; i++) {


    int x=70;
    int y=70+(i/2)*100;

    if ((i&2) != 0) x+=50;

    int spacingX = 100;
    int sphereOffsetX = 140;
    if ((i%2)==1) {
      spacingX = -100;
      sphereOffsetX = -120;
      x+=960+600;
    }

    controlBoards[i]=new RS485LeonardoController(x, y, i, true, spacingX, sphereOffsetX);
    int topUnitID = i+(controlBoardCount/2);
    controlBoards[topUnitID]=new RS485LeonardoController(x, y, topUnitID, false, spacingX, sphereOffsetX);
  }

  if (enableOSC) {
    oscP5 = new OscP5(this, 7401);
    myRemoteLocation1 = new NetAddress(partnerIP, 7400);
    myRemoteLocation2 = new NetAddress(partnerIP, 7401);
  }

  try {
    InetAddress inet;
    inet = InetAddress.getLocalHost();
    myIP = inet.getHostAddress();
  }
  catch (Exception e) {
  }
}

void draw() {
  accuTime = 0;
  //long stampTime = System.nanoTime();

  if (frameCount%15==0) {
    //hotplug stuff
    {
      int i=0;
      while (i<hotplugSerials.size()) {
        HotPlugSerial onePort=hotplugSerials.get(i);
        if (onePort.update()) {
          println("Remove "+onePort.serialName+" due to inactivity");
          hotplugSerials.remove(i);
          continue;
        }
        i++;
      }
    }

    for (int i=0; i<hotplugSerials.size(); i++) {
    }

    SerialHandler_checkSerialPort();  //Serial.list() is slow, no need to run every frame
  }

  background(0);
  fill(255);
  text(int(frameRate), 20, 700);
  text("myIP: "+myIP+"  partnerIP: "+partnerIP, 20, 720);

  synchronized (effectObjects) {
    effectObjects.update();  //this give all spheres color
    effectObjects.draw();

    {
      for (int i=0; i<controlBoards.length; i++) {  //draw board
        controlBoards[i].update();
        controlBoards[i].draw();
      }
    }
  }

  //accuTime+=System.nanoTime()-stampTime;
  //println("Draw us", (accuTime)/1000);
}

void serialEvent(Serial port) {
  int i;
  String inString = port.readString();
  inString = inString.substring(0, inString.length() - 1);
  for (i=0; i<hotplugSerials.size(); i++) {
    HotPlugSerial onePort=hotplugSerials.get(i);
    if (onePort.serial==port) {
      onePort.processInput(inString);
      break;
    }
  }
  if (i>=hotplugSerials.size()) {
    println("Data from unregisterd port: ");
    println(inString);
  }
}

void keyPressed() {
  if (key == 'd') {
    //print some debug info
    println("hotplugSerials has "+hotplugSerials.size()+" elements");

    String[] cmd = {
      "/bin/sh", "-c", "system_profiler SPUSBDataType | grep Leonardo -c"
    };

    Process p = exec(cmd);
    String lineBuf="-1";  
    try {
      String line;
      BufferedReader input =  
        new BufferedReader  
        (new java.io.InputStreamReader(p.getInputStream()));  
      while ((line = input.readLine()) != null) {
        lineBuf=line;
      }  
      input.close();
    } 
    catch (Exception e) {
    }
    int lineNumber = Integer.valueOf(lineBuf);
    println("Leonardo on USB tree: ", lineNumber);
  }

  if (key=='f') {  //reset usb hub
    String[] cmd = {
      "/bin/sh", "-c", "~/Downloads/reenumerate -v 0x05e3,0x0610"
    };

    Process p = exec(cmd);
  }

  if (key == 'r') {  //reset calibration
    for (int i=0; i<controlBoards.length; i++) {
      controlBoards[i].resetCalibration();
    }
  }
  if (key == 'c') {
    for (int i=0; i<controlBoards.length; i++) {
      controlBoards[i].setCalibration();
    }
  }

  if (key == 't') {
  }

  if (key == 'w') {  //test
    effectObjects.addWave(100, HALF_PI, false);
    effectObjects.addWave(100, HALF_PI, true);
  }

  if (key == 'o') {  //test
    effectObjects.addRipple(500, 500, true, true);
  }

  if (key == 'b') {  //test
    effectObjects.addBreath(false);
  }
}

void oscEvent(OscMessage theOscMessage) {
  if (theOscMessage.checkAddrPattern("/ripple")==true) {
    /* check if the typetag is the right one. */
    if (theOscMessage.checkTypetag("ffi")) {
      /* parse theOscMessage and extract the values from the osc message arguments. */
      float xpos = theOscMessage.get(0).floatValue();
      float ypos = theOscMessage.get(1).floatValue();
      int onFloorValue = theOscMessage.get(2).intValue();  
      boolean onGround = (onFloorValue !=0);
      synchronized (effectObjects) {
        effectObjects.addRipple(xpos, ypos, !onGround, false);
      }
      //println("### OSC ripple", xpos, ypos, !onGround);
    }
  } else {
    println("### received an osc message with addrpattern "+theOscMessage.addrPattern()+" and typetag "+theOscMessage.typetag());
    theOscMessage.print();
  }
}

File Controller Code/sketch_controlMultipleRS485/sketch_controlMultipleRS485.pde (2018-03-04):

import processing.serial.*;

Serial myPort;       

//int boardsID[]={1, 2, 3};
LEDSphere spheres[] = new LEDSphere[1];
int boardIndexOffset = 9;

int boardCheckingIndex = 0;

interface CheckStates {
  int
    IDLE=0, 
    INQUIRED=1, 
    RESPONSED=2, 
    TIMEOUT=3;
}

int boardCheckInquireTime = 0;

int boardCheckStates = CheckStates.IDLE;

void setup() {

  for (int i=0; i<spheres.length; i++) {
    spheres[i] = new LEDSphere(i+boardIndexOffset, 150+300*i, 150);
  }

  String validPort="";
  String[] allPorts=Serial.list();
  for (String port : allPorts ) {
    if (port.startsWith("/dev/tty") && (port.startsWith(".usbmodem", 8) || port.startsWith(".usbserial", 8))) {
      validPort=port;
    }
  }
  println(validPort);

  if (validPort.length()>0) {
    myPort = new Serial(this, validPort, 115200);
    myPort.bufferUntil('\n');
  }

  size(600, 300);
  frameRate(60);
}


void draw() {
  background(0);

  LEDSphere oneSphere=spheres[boardCheckingIndex];
  int id= oneSphere.id;
  switch (boardCheckStates) {
  case CheckStates.IDLE:
    String checkOutput = String.format("E%02X\n", id);  //weird new line needed?
    //println(checkOutput);
    myPort.write(checkOutput);
    boardCheckStates=CheckStates.INQUIRED;
    boardCheckInquireTime=millis();
    break;
  case CheckStates.INQUIRED:
    if ((millis()-boardCheckInquireTime)>20) {
      boardCheckStates=CheckStates.TIMEOUT;
      oneSphere.lost=true;
      oneSphere.timeLost=millis();
      //println("TIMEOUT first");
    }
    break;

  case CheckStates.RESPONSED:
    oneSphere.lost=false;
    oneSphere.timeoutLimit=100;
    //println("RESPONSED");
  case CheckStates.TIMEOUT:
    if (boardCheckStates==CheckStates.TIMEOUT) {
      //println("TIMEOUT "+oneSphere.id);
      oneSphere.timeLost = millis();
      oneSphere.timeoutLimit=oneSphere.timeoutLimit*100+(int)random(100);
      if (oneSphere.timeoutLimit>30000) oneSphere.timeoutLimit =30000;
    }
    boardCheckStates = CheckStates.IDLE;
    //while (1) {
    boardCheckingIndex++;
    if (boardCheckingIndex>=spheres.length) boardCheckingIndex=0;
    //}
    break;
  default:
    break;
  }


  for (int i=0; i<spheres.length; i++) {
    spheres[i].draw();
  }
}

void serialEvent(Serial p) {
  String inString = p.readString().trim();
  //println(inString);
  try {
    char firstChar = inString.charAt(0);
    if (firstChar=='S') {
      if (inString.length() == 15) {
        String idStr = inString.substring(1, 3);

        String xStr = inString.substring(3, 7);
        String yStr = inString.substring(7, 11);
        String zStr = inString.substring(11, 15);
        int id=Integer.parseInt(idStr, 16);
        int x=Integer.parseInt(xStr, 16);
        if (x>32767) x=x-65536;
        int y=Integer.parseInt(yStr, 16);
        if (y>32767) y=y-65536;      
        int z=Integer.parseInt(zStr, 16);
        if (z>32767) z=z-65536;
      }
    } else if (firstChar=='E') {
      if (inString.length() == 13) {
        println(millis()-boardCheckInquireTime);
        
        String idStr = inString.substring(1, 3);
        String eventStr = inString.substring(3, 5);
        String xStr = inString.substring(5, 9);
        String yStr = inString.substring(9, 13);
        int id=Integer.parseInt(idStr, 16);
        int x=Integer.parseInt(xStr, 16);
        if (x>32767) x=x-65536;
        int y=Integer.parseInt(yStr, 16);
        if (y>32767) y=y-65536;      
        int eventID=Integer.parseInt(eventStr, 16);

        LEDSphere oneSphere=spheres[boardCheckingIndex];

        if (oneSphere.id == id) {
          oneSphere.updateData(x, y, eventID); 
          //println(eventID);
        } else {
          //println("ID mismatch");
        }
        if (boardCheckStates == CheckStates.INQUIRED) {
          boardCheckStates = CheckStates.RESPONSED;
          if (oneSphere.needUpdateParameter>0) {
            String paraOutput = String.format("P%02X%04X%04X%04X\n", id, oneSphere.envelopeRate, oneSphere.envelopeThreshold, oneSphere.centerThreshold);
            myPort.write(paraOutput);
            //println(paraOutput);
            oneSphere.needUpdateParameter--;
          } else {
            String ledOutput = String.format("L%02X%02X%02X%02X\n", id, oneSphere.fillcolorDim >> 16 & 0xFF, oneSphere.fillcolorDim >> 8 & 0xFF, oneSphere.fillcolorDim >> 0 & 0xFF);
            myPort.write(ledOutput);
          }
        }
      }
    } else {
      println(inString);
    }
  }
  catch(Exception e) {
    e.printStackTrace();
  }
}

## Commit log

2017-12-21 Initial Commit
    Added all the current working files.
    [5VSwitchablePowerOutput.brd, 5VSwitchablePowerOutput.sch, ENC28J60Breakout_V02.brd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]
2017-12-23 add 1st version of file
    [rs485board.brd, rs485board.sch]
2017-12-24 add more traces
    [rs485board.brd, rs485board.sch]
2017-12-27 adjust wires
    [rs485board.brd, rs485board.sch]
2017-12-27 add copper and text
    [rs485board.brd]
2017-12-28 add values
    [rs485board.brd, rs485board.sch]
2017-12-28 add value and gerber
    [rs485board.brd, rs485board.sch]
2018-01-08 add support file
    [support.SLDPRT, support.STL]
2018-01-09 temp bug walk around
    [sketch_controlMultipleRS485.pde]
2018-01-09 adaptor board
    [rs485Adaptor.brd, rs485Adaptor.sch]
2018-01-09 add gerber
2018-01-16 add note
    [rs485board.sch]
2018-03-12 mills work
2018-03-15 add resistor
    [rs485board.brd, rs485board.sch]
2018-03-15 back up
    [rs485board.brd, rs485board.sch, support.SLDPRT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]
2018-03-16 48V upgrade
    [rs485board.brd, rs485board.sch]
2018-04-02 Prototype Demo Code
    Processing demo code for the initial prototype.
2018-04-04 add lcsc part number
    [rs485board.brd, rs485board.sch]
2018-04-26 add some reference
    [depanelizeTest.SLDPRT, depanelizeTest.STL]
2018-04-26 duplicate board and try array_board ulp
    [rs485boardPanelize.brd]
2018-04-26 remove copper fill on 5V
    [rs485board.brd]
2018-04-26 ready to panelize
    [rs485boardPanelize.brd]
2018-04-27 adjust spacing
    [rs485boardPanelize.brd]
2018-04-27 clean up 2*2
    [rs485boardPanelize.brd]
2018-04-27 move to AB 2*2
    [rs485boardPanelize.brd]
2018-04-27 panel finish, need add fiducial
    [rs485boardPanelize.brd]
2018-04-27 add fiducial
    [rs485boardPanelize.brd]
2018-04-27 reduce tab size
    [rs485boardPanelize.brd]
2018-04-27 fix text
    [rs485boardPanelize.brd]
2018-04-27 export gerber
2018-05-07 start working on BOM
    [BOM.xlsx]
2018-05-07 finish bom
    [BOM.xlsx]
2018-05-07 add adaptor board
    [micropro485Adaptor.brd, micropro485Adaptor.sch]
2018-05-18 add calibration
2018-06-09 update power on pattern
2018-06-13 add boards
2018-08-31 fix send offset wrong loop bug
    [RS485LeonardoController.pde]
2018-08-31 remove position print
2018-09-01 fix long buffer fail bug
    [sketch_485Board.ino]
2018-09-04 start working on auto reset of Leonardo
    [RS485LeonardoController.pde, eeprom_write.ino, sketch_controlMultipleRS485ThroughLeonardo.pde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]
2018-09-04 add marco for auto reset
    [sketch_leonardoController.ino]
2018-09-04 fix CDC mess with WDT
    [sketch_leonardoController.ino]
2018-09-04 disable error print
2018-09-04 add test LED code
2018-09-05 count time when board connects
2018-09-05 fix fast packet lost issue
    [RS485LeonardoController.pde, sketch_leonardoController.ino]
2018-09-05 add timer for performance
2018-09-05 remove additional buffer as Arduino can buf
2018-09-12 add 3d model to help solder
    [supportSolder.SLDPRT]
2018-09-22 add auto-reconnect python to check board ID
2019-04-30 auto reset is getting problem
    [sketch_leonardoController.ino]
2019-05-02 edit effect, add reset command
    [EffectObjects.pde, sketch_controlMultipleRS485ThroughLeonardo.pde]

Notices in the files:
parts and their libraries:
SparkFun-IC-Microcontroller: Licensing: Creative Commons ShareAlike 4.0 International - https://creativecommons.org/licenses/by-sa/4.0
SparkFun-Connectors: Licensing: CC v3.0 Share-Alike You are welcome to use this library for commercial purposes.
